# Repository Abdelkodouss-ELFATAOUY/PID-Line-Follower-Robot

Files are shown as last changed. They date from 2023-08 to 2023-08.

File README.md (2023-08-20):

# PID-Line-Follower-Robot
Study and production of a line follower with PID regulation: 
- ✓ Line follower with PID.
- ✓ Control by smartphone. 
- ✓ Detector of obstacles in an environment.



# IR Matrix Sensor


# video 
- Robot Finale :
- https://github.com/Abdelkodouss-ELFATAOUY/PID-Line-Follower-Robot/assets/142337040/76032142-d66d-45df-a297-c0f8cd918390
- https://github.com/Abdelkodouss-ELFATAOUY/PID-Line-Follower-Robot/assets/142337040/5c52f689-e024-426b-826d-6eb9a237bb47

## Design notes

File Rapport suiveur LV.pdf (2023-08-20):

UNIVERSITE SULTAN MOULAY SLIMANE

FACULTE DES SCIENCES ET TECHNIQUES

BENI-MELLAL

Licence Ingénierie Electronique et Télécommunication

Rapport de Projet de Fin d’Etudes

Présenté par

ELFATAOUY Abdelkodouss

AHARHAR Mohammed

Réalisé au sein de la FST Béni-Mellal

Encadré par : Pr. El-Hocine AGOURIANE

Soutenue publiquement le JJ /06/2021 devant le jury :

Etude et réalisation d’un suiveur de piste avec régulation PID

NOM1 | Président
NOM2 | Examinateur
Pr. El-Hocine AGOURIANE | Encadrant

Remerciement

En premier lieu, nous tenons à remercier ‹‹ DIEU › › pour nous avoir donner le courage et la

patience durant nos années d’études.

En second lieu, nous adressons nos reconnaissances à notre encadrant AGOURIANE EL-

Hocine Professeur à la faculté des sciences et techniques Béni-Mellal pour son aide précieuse,

son encadrement de qualité et ses directives qui nous ont été d’une grande utilité afin

d’accomplir notre projet de fin d’études.

Nous tenions également à remercier le professeur L. OUFNI chef du département de physique,

pour avoir permis de mener ce travail dans de bonnes conditions.

Enfin, nous exprimons nos remerciements, les plus dévoués, au professeur MABROUKI

Mustapha responsable de la formation ainsi qu’aux membres de jury pour avoir accepté de

juger notre modeste projet de fin d’études.

Dédicace

Nous dédions ce modeste travail

À nos chers parents

pour leur soutien, leur patience, leur sacrifice,

et leur amour, vous méritez tout éloge.

Vous qui avez fait de nous ce que nous sommes aujourd’hui.

Nous espérons être l’image que vous avez fait de nous, que dieu vous garde et vous bénisse.

Nous dédions aussi ce travail à nos chers frères et sœurs,

pour leur affection et leur encouragement qui ont toujours

été pour nous des plus précieux.

Que ce travail soit pour vous le gage de notre profond amour.

A tous nos amis,

A tous ceux qui nous ont aidés,

A tous ceux que nous aimons, nous dédions ce travail.

Sommaire

Chapitre II : L’étude du régulateur PID et description de fonctionnement du suiveur de piste

III.3.2. Installation du robot manuellement sur une piste et réglage des coefficients du régulateur PID à

Résume

Le but de ce projet est l’étude et la réalisation d’un robot autonome avec PID,

capable de suivre une piste et éviter les obstacles, offrant la possibilité de le commander

en utilisant un mode Bluetooth de contrôle à distance. Ce robot est à base d'un

microcontrôleur Arduino Uno, de capteurs de lumières, capteur ultrasonique ainsi que d’un

driver de puissance pour alimenter les moteurs qui assurent le déplacement du robot à

travers le mécanisme que nous avons réalisé. Son rôle est de développer les capacités

d'action des humains dans des environnements hostiles ou inaccessibles, et transporter les

produits dans le domaine industriel.

Liste des tableaux

TABLEAU 1: CARACTERISTIQUES DE LA CARTE ARDUINO UNO _______________________________________ 26 TABLEAU 2:TABLEAU : LE FONCTIONNEMENT DES BROCHES ________________________________________ 29 TABLEAU 3:LA TABLE DE VERITE DE FONCTIONNEMENT DE CONTROLE D’UN MOTEUR ___________________ 30 TABLEAU 4: FONCTION DE SUIVEUR DE PISTE ____________________________________________________ 38 TABLEAU 5:LES DEFAUTS DE ROUE DE GUIDAGE __________________________________________________ 46 TABLEAU 6: DESCRIPTION LES DIFFERENTS TYPES DE COMMUNICATION ______________________________ 48 TABLEAU 7:LES CAPTEURS INFRAROUGES IR _____________________________________________________ 50 TABLEAU 8:LES BROCHES DE CAPTEUR ULTRASON : _______________________________________________ 50 TABLEAU 9:LES BROCHES DE CAPTEUR ULTRASON : _______________________________________________ 50 TABLEAU 10:LES BROCHES DE CARTE BLUETOOTH ________________________________________________ 51 TABLEAU 11:LA CONNEXION ENTRE ARDUINO ET DRIVER MOTEUR DU PONT H_________________________ 51 TABLEAU 12: DESCRIPTION DE DIFFERENTES TACHES DE ROBOT _____________________________________ 53

Liste des figures

FIGURE 1:QUELQUES APPLICATIONS DES ROBOTS MOBILES __________________________________________ 4 FIGURE 2:DIFFERENTES STRUCTURES MECANIQUES DES ROBOTS _____________________________________ 5 FIGURE 3:REPONSE D’UN CAPTEUR ANALOGIQUE__________________________________________________ 6 FIGURE 4:REPONSE D’UN CAPTEUR NUMERIQUE __________________________________________________ 6 FIGURE 5:REPONSE D’UN CAPTEUR LOGIQUE _____________________________________________________ 7 FIGURE 6:FONCTIONNEMENT D'UN ACTIONNEUR__________________________________________________ 7 FIGURE 7:SCHEMA BLOC DU MOTEUR REDUCTEUR ________________________________________________ 8 FIGURE 8:ASSERVISEMENT DE SYSTEME_________________________________________________________ 12 FIGURE 9:LA STABILITE D'UN SYSTEME__________________________________________________________ 12 FIGURE 10: LA PRECISION D'UN SYSTEME _______________________________________________________ 13 FIGURE 11: LA RAPIDITE D'UN SYSTEME_________________________________________________________ 13 FIGURE 12:AOP NON INVERSEUR ______________________________________________________________ 14 FIGURE 13:PROPORTIONNALITE D’ERREUR ______________________________________________________ 14 FIGURE 14: L’ERREUR ENTRE LA CONSIGNE DESIREE ET DE MESURE __________________________________ 15 FIGURE 15: AOP DERIVATEUR _________________________________________________________________ 15 FIGURE 16: LA DERIVEE D’ERREUR _____________________________________________________________ 16 FIGURE 17: STABILITE DE SIGNAL PAR ACTION DERIVEE ____________________________________________ 16 FIGURE 18: AOP INTEGRATEUR________________________________________________________________ 17 FIGURE 19: L’INTEGRATION D’ERREUR __________________________________________________________ 17 FIGURE 20: LA PRECISION DE SIGNAL PAR ACTION INTEGRAL________________________________________ 17 FIGURE 21: LE SYSTEME ASSERVI ANALOGIQUE INSERE PAR LE REGULATEUR. __________________________ 18 FIGURE 22: L’ECHANTILLONNAGE D’UN SIGNAL __________________________________________________ 18 FIGURE 23: SYSTEME ASSERVI NUMERIQUE______________________________________________________ 19 FIGURE 24: L’INTEGRALE NUMERIQUE __________________________________________________________ 20 FIGURE 25: LA DERIVE NUMERIQUE. ___________________________________________________________ 21 FIGURE 26:DIAGRAMME SCHEMATIQUE DU SUIVEUR _____________________________________________ 22 FIGURE 27:SCHEMA ELECTRONIQUE DU CAPTEUR INFRAROUGE _____________________________________ 23 FIGURE 28: SCHEMA BLOC DE FONCTIONNEMENT DU CAPTEUR A ULTRASON __________________________ 24 FIGURE 29: STRUCTURE DE LA CARTE ARDUINO UNO ______________________________________________ 25 FIGURE 30: LE CAPTEUR BLUETOOTH HC-06 _____________________________________________________ 27 FIGURE 31: LES PILES DE LITHIUM______________________________________________________________ 27 FIGURE 32: L’EMPLACEMENT DU DRIVER DANS LA CHAINE. _________________________________________ 28 FIGURE 33: DESCRIPTION DIFFERENTE COMPOSANTES DU DRIVER MOTEUR ___________________________ 28 FIGURE 34: SCHEMA ELECTRONIQUE DE PONT EN H_______________________________________________ 29 FIGURE 35: SCHEMA BLOC DE FONCTIONNEMENT DES ENGRENAGES _________________________________ 30

FIGURE 36: LA COUPE DU MOTEUR MCC ________________________________________________________ 31 FIGURE 37: APP INVENTOR ET LANGAGE SCRATCH ________________________________________________ 32 FIGURE 38: LES PIECES DE ROBOT______________________________________________________________ 34 FIGURE 39: LE MONTAGE DE CHASSIS DE ROBOT _________________________________________________ 34 FIGURE 40: LES CARTES ELECTRONIQUES ________________________________________________________ 35 FIGURE 41: CAPTEUR INFRAROUGE ____________________________________________________________ 36 FIGURE 42: SIMULATION SOUS ISIS DU CAPTEUR AVEC UN MOTEUR__________________________________ 36 FIGURE 43: LE ROBOT SUIVEUR DE PISTE ________________________________________________________ 37 FIGURE 44: LE PROBLEME DE CONNEXION DES CAPTEURS INFRAROUGE ______________________________ 40 FIGURE 45: CIRCUIT IMPRIME DES CAPTEURS INFRAROUGES ________________________________________ 40 FIGURE 46: APPLICATION POUR CONTROLER LE ROBOT PAR BLUETOOTH______________________________ 41 FIGURE 47: ASPECT DE L’APPLICATION ANDROID REALISEE _________________________________________ 41 FIGURE 48: ALGORITHME DE L’APPLICATION BLUETOOTH __________________________________________ 43 FIGURE 49: LE ROBOT NE DETECTE PAS L’OBSTACLE _______________________________________________ 43 FIGURE 50: ASPECT ET FONCTIONNEMENT DU CAPTEUR ULTRASON__________________________________ 43 FIGURE 51: ILLUSTRATION DE FONCTIONNEMENT DU CAPTEUR _____________________________________ 44 FIGURE 52: LA STRUCTURE DE BRANCHEMENT DU CHARGEUR ______________________________________ 45 FIGURE 53: LE CHARGEUR DE BATTERIE LITHIUM REALISE __________________________________________ 45 FIGURE 54: LA STRUCTURE DE CHARGER DES PILES________________________________________________ 46 FIGURE 55: LA CONFIGURATION DE LA BATTERIE REALISEE. _________________________________________ 46 FIGURE 56: SCHEMA SYNOPTIQUE DE L’ENSEMBLE DU SUIVEUR DE PISTE _____________________________ 48 FIGURE 57: LE BRANCHEMENT DES COMPOSANTS DU ROBOT PAR LOGICIEL FRITZING ___________________ 50 FIGURE 58: VUE AU-DESSOUS DE ROBOT ________________________________________________________ 52 FIGURE 59:VUE AU-DESSUS DE ROBOT__________________________________________________________ 52 FIGURE 60: LES MULTITACHES DE ROBOT _______________________________________________________ 53

Introduction générale

Depuis bien longtemps, l’Homme rêve de créer des machines intelligentes capables

d’effectuer des tâches à sa place. Ainsi, les humains auraient plus de temps à consacrer

pour leurs loisirs, ou prendraient moins de risques pour effectuer des tâches dangereuses

dans des endroits inaccessibles et hostiles. La robotique est l’ensemble des techniques

permettant la conception et la réalisation de ces machines appelées « robots ». Un robot est

un appareil effectuant, grâce à un système de commande automatique à microprocesseur,

une tâche précise pour laquelle il a été conçu dans le domaine industriel, domestique ou

scientifique.

Dans ce travail on va se focaliser sur les robots mobiles, qui sont largement utilisés

dans les environnements industriels, le plus souvent pour effectuer des tâches répétitives

et pénibles. L’intérêt principal des robots mobiles est de permettre aux êtres humains

d’effectuer des tâches dangereuses dans des endroits inaccessibles. C’est pour cela que

l’un des domaines les plus populaires où les robots mobiles sont utilisés est le domaine

scientifique.

Afin d’être autonome, un robot mobile doit posséder de nombreuses capacités.

Premièrement, il doit être capable de percevoir son environnement et de se localiser dans

celui-ci. Pour ce faire, il doit être doté de plusieurs capteurs. Une fois localisé dans son

environnement, le robot doit être capable de se déplacer d’un point à un autre en trouvant

des chemins dégagés et sécurisés afin d’éviter des collisions avec les obstacles, pour cela

les robots mobiles utilisent plusieurs moyens de locomotion selon l’environnement auquel

ils sont destinés. De plus, un robot est appelé à communiquer avec son environnement ou

avec des agents situés à proximité et cela peut être fait par une interface wifi,

Bluetooth…etc.

Le but de ce travail est la conception et réalisation d’un suiveur de piste doté d’une

régulation PID en plus télécommandé à distance par Bluetooth et qui a la possibilité de

détecteur des obstacles et d’être autonome. Pour le réaliser on a utilisé une carte Arduino

UNO qui représente le cerveau du robot munis de différents capteurs qui vont lui permettre

la perception, il sera doté de moteurs et roues pour le déplacement, puis un régulateur PID qui pilote le suiveur de piste afin d’amélioration les performances, ainsi qu’un moyen de

communication par voie Bluetooth qui offre une possibilité de contrôle à distance.

Ce travail est organisé de la façon suivante :

- Le premier chapitre est consacré à des généralité sur les robots mobiles et la

structure robotique.

- Le deuxième chapitre présente la notion de système asservis et l’étude de la

régulation automatique PID.

- Le troisième chapitre est dédié à la réalisation et conception du robot suiveur

de pise.

Chapitre I : Généralités sur la Robotique

## Chapitre I : Généralités sur la Robotique

Introduction

La robotique est une science à la croisée de plusieurs disciplines scientifiques et

techniques (informatique, mécanique, automatique et électronique) permettent la

conception et la réalisation des robots qui vise à rendre une machine autonome.

I.1. Généralités sur les robots mobiles

Les robots mobiles sont des robots capables de se déplacer dans leur

environnement.

I.1.1. Définition d’un robot mobile

Un robot est une machine qui est équipée de capacités de perception, de décision et

d’action qui lui permettent d’agir de manière autonome dans son environnement en

fonction des informations collectées par ses différents capteurs.

L’appellation Robot mobile regroupe aussi un ensemble de programmes associés,

dont les mouvements sont synchronisés et commandés numériquement. Il n’est donc

qu’une machine programmable qui ne fait qu’exécuter ce que l’homme lui a programmé.

I.1.2. Classification des robots mobile

La classification des robots mobiles se fait selon plusieurs critères :

- Degré d'autonomie ;
- Système de locomotion ;
- Énergie utilisée.

La classification la plus intéressante et la plus utilisée est selon le degré

d'autonomie. Un robot mobile autonome est un appareil capable de se déplacer par ses

propres moyens, dotés de capacités décisionnelles et de moyens d'acquisition et de

traitement de l'information qui lui permettent d'accomplir, sous un contrôle humain réduit,

un certain nombre de tâches dans un environnement complètement inconnu.

I.1.3. Types de robots :

- Robot télécommandé par un opérateur :

Chapitre I : Généralités sur la Robotique

Ces robots sont commandés par un opérateur qui leur impose chaque tâche élémentaire

à réaliser.

- Robot télécommandé au sens de la tâche à réaliser :

Le véhicule contrôle automatiquement ses actions.

- Robot semi- autonome :

Ce type de robot réalise des tâches prédéfinies.

- Robot autonome :

Ce type de robot réalise des tâches semi-définies, il pose des problèmes d’un niveau

de complexité élevé de représentation des connaissances, de capacité décisionnelle et de

génération de plans qui sont résolus à bord dans la mesure du possible.

I.1.4. Les applications

Les applications des robots sont diverses et dons plusieurs domaines.

- Véhicules autoguidés ou VAG (https://www.mecalux.fr/cours-logistique-entrepot/engins-de-manutention/vehicule-a-guidage-automatique-agv-vga)
- Robot explorateur
- Robot de service
- Robot ludique
- Robot de Surveillance
- Robot mobile de tri
- Robot quadrupède

Figure 1:Quelques applications des robots mobiles

I.1.5. Les avantages dans l’utilisation du robot mobile

L'utilisation de robots mobiles présente ces principaux avantages :

Robot AVG | Robot explorateur | Robot de tri

Chapitre I : Généralités sur la Robotique

- Remplacement de l’homme dans l’exécution des tâches complexes et

répétitives.

- Accroissement de la capacité de production.
- Déplacement sans conducteur.

I.2. La structure mécanique et motricité

Il existe quatre types de structures mécaniques assurant la motricité des robots :

- Les robots à roues.
- Les robots à chenilles.
- Les robots marcheurs.
- Les robots à pattes.

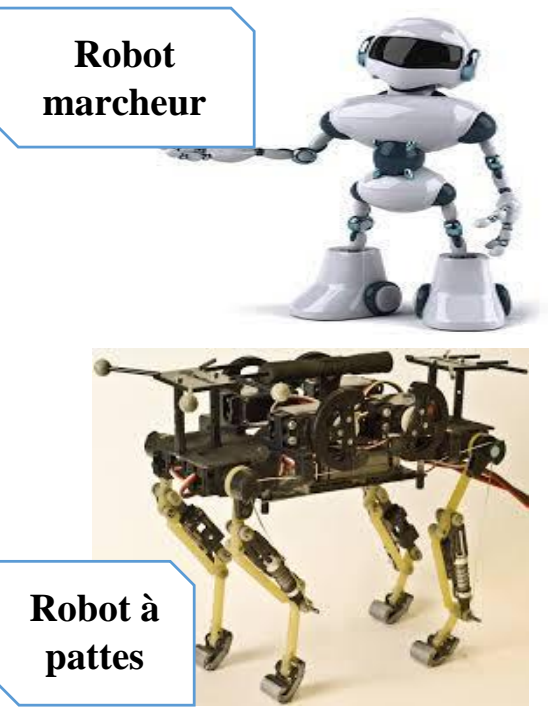
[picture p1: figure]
Robot marcheur; Robot à pattes

Figure 2:Différentes structures mécaniques des robots

I.3. Les composants d’un robot

Un robot mobile est constitué de composantes matérielles et logiciels. Parmi ces

composants on retrouve les capteurs, les actionneurs, carte de traitement et une source

d’énergie.

I.3.1 Les capteurs

Les capteurs sont des transducteurs qui permettent d’acquérir des données

provenant d’environnement pour mesurer une grandeur physique (température, obstacle,

Chapitre I : Généralités sur la Robotique

vitesse, humidité, pression, niveau, débit, ...) en générale en la transformant en une

grandeur électrique.

I.3.1.1 Classification des capteurs

Selon la nature du signal ou l’information de sortie des capteurs on peut les classer

en trois catégories :

I.3.1.1.1 Le signal analogique

L’information peut prendre toutes les valeurs possibles entre deux certaines valeurs

limites pouvant être courant ou tension, on parle alors d’un capteur analogique.

Figure 3:Réponse d’un capteur analogique

I.3.1.1.2 Le signal numérique (https://fr.wikipedia.org/wiki/Num%C3%A9rique)

L’information fournie par le capteur est un nombre binaire codé sur n bits pouvant

être un train d’impulsion, code numérique binaire. On parle alors d’un codeur numérique.

Figure 4:Réponse d’un capteur numérique

Chapitre I : Généralités sur la Robotique

I.3.1.1.3 Le signal logique

L’information ne peut prendre que la valeur 1 ou 0. On parle alors d’un détecteur

Tout Ou Rien "TOR". Il est très répondu dans les systèmes automatisés et est classé en

deux familles :

- Capteurs avec contact ou détecteur de position.
- Capteurs sans contact ou détecteurs de proximité.

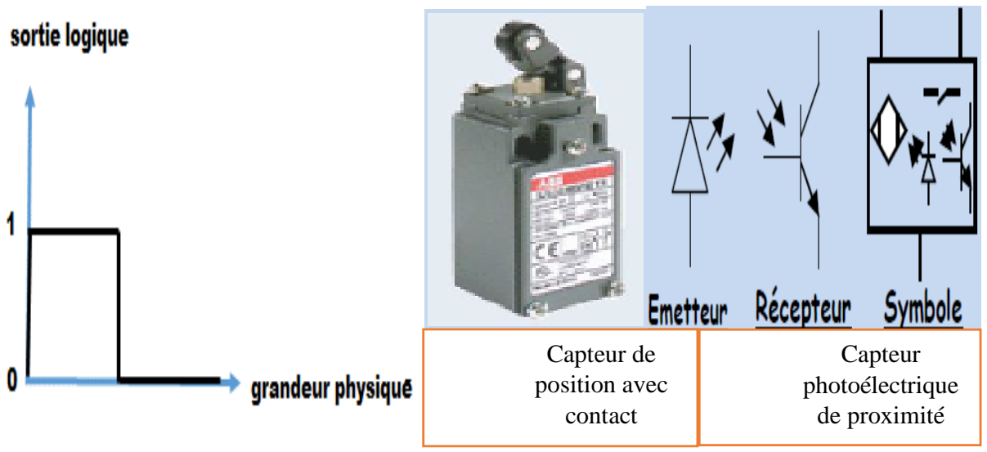
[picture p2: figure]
Capteur photoélectrique de proximité; Capteur de position avec contact

Figure 5:Réponse d’un capteur logique

I.3.2 Les actionneurs

Les actionneurs sont situés dans la partie opérative d’un système automatisé. Ils

font partie de la chaine d’action de ce système. Les actionneurs transforment l’énergie de

puissance fournie du système en énergie mécanique pour déplacer une machine.

Figure 6:Fonctionnement d'un actionneur

I.3.2.1 Le type d’actionneurs I.3.2.1 1 Moteur à courant continue

Un moteur continu appelé également moteur DC, transforme une énergie

électrique en une énergie mécanique. Il sert notamment à faire tourner les roues d'un

système de façon "constante".

Energie | Actionneur
électrique

Energie
mécanique

Energie de
contrôle

Chapitre I : Généralités sur la Robotique

Son Inconvénient est son faible couple mécanique. Pour augmente le couple il faut

Figure 7:Schéma bloc du moteur réducteur

- Pe
: Puissance électrique.
- Pm : Puissance mécanique.
- R : le rapport de réduction.
- r< 1 : réduit la vitesse angulaire.
- r> 1 :multiplie la vitesse angulaire.
- Pe=UI=Pm=Cmωe

→ Cm=

Pe
| ωe
Pour augmenter le couple il faut diminuer la vitesse angulaire.

I.3.2.1.2 Servomoteur

Un servomoteur est un moteur continu équipé d'un réducteur (des engrenages),

dont l'objectif est de réduire la vitesse et d'augmenter le couple (la puissance), il est doté

d’un potentiomètre qui permet au servomoteur de garder l’angle d’inclinaison choisit. En

effet, l’un des intérêts des servomoteurs c’est de leur faire prendre et garder un angle.

Pour contrôler un servomoteur, il suffit de lui envoyer une impulsion de quelques

millisecondes qui se répète à intervalle régulier (ce que l’on appelle la période), et dont

la durée détermine l’angle de rotation de l’axe du servomoteur.

Par exemple une impulsion de:

1,25 ms = 0 degré

1,50 ms = 90 degrés

1,75 ms = 180 degrés

Chapitre I : Généralités sur la Robotique

Conclusion

Dans ce chapitre a étalé les notions de base de la robotique mobile, quelques types

d’applications et de classification ont été présentés. Dans la suite certains points seront

détaillés, car ils sont plus étroitement liés au présent projet.

Chapitre II : L’étude de régulateur PID et Description de fonctionnement du suiveur de piste

## Chapitre II : L’étude du régulateur PID et description de fonctionnement du suiveur de piste

Introduction

Pour être compétitif, un procédé industriel doit être obligatoirement automatisé. En

effet, la compétitivité exige de le maintenir le plus près possible de son optimum de

fonctionnement prédéfini par un cahier des charges qui fixe les conditions et performances

imposées. La régulation occupe généralement la grande partie de l’automatisation d’un

procédé industriel. Actuellement, il est impossible de rencontrer un procédé industriel

n’utilisant pas de régulation. Cela veut dire que la régulation industrielle est plus

qu’indispensable pour le bon fonctionnement et donc pour la compétitivité de tout procédé

industriel. Le contrôle en boucle fermée, régulation ou asservissement, est le plus populaire

au sein de la majorité des industriels. Dans le cadre de notre projet de fin d’études,

l’objectif du travail qui nous a été proposé est de faire l'étude de la régulation

proportionnelle, intégrale, dérivée ou PID sur le suiveur de piste afin d’optimiser les

performances du suiveur de piste.

Dans ce chapitre, après un bref historique sur la régulation PID, nous allons donner

quelques rappels sur l’asservissement et sur la régulation et leurs objectifs. Nous allons

aussi discuter sur la typologie de la régulation qui comprend deux types : régulation

analogique et régulation numérique qui ont le même principe de fonctionnement.

Partie I : Généralités sur la régulation PID : analogique et Numérique

II.1 Historique de contrôleur PID

Nicolas Minorsky est né en septembre1885 à

Korcheva, Russie et il est mort à l’âge de 85 ans le 31 juillet

1970, en Italie. I a fait ses études à l’école navale. Il a fait des

études en génie électrique et en sortit en 1914 avec un doctorat

en sciences appliquées, il a servi dans la Marine russe et a été

pendant un an adjoint et il a immigré vers l’américain et a

travaillé dans le domaine de l’électronique et de la physique

applique en tant que professeur universitaire. Pendant la guerre il a travaillé en grande

Chapitre II : L’étude de régulateur PID et Description de fonctionnement du suiveur de piste

partie sur des problèmes de stabilité, c’est durant cette période qu’il s’intéressé de plus en

plus aux systèmes non linéaires. En 1946 il rejoint la division de l’ingénieure mécanique

pour continuer à travailler sur les problèmes de stabilisation des navires, sur son article

« stabilité directionnelle des corps a direction automatique » Minorisky intervient au

croisement de trois domaines : La mécanique, l’électricité et les mathématiques.

Minorsky a étudié le comportement mathématique des équations différentielles de

mécanisme des navires c’est pour trouver des paramètres principaux au domaine

d’électricité afin de piloter des navires automatiquement.

II.2 Définition de l’automatique.

L'automatique est une science qui traite de la modélisation, de l'analyse, de l'

identification et de la commande des systèmes dynamiques.

Un automaticien doit être à la fois :

- Mathématicien.
- Electricien.
- Mécanicien.
- Informaticien.

II.2.1 Système automatisé

Un système automatisé est un système réalisant des opérations et pour lequel

l'homme n'intervient que dans la programmation du système et dans son réglage.

II.2.2 Système linéaire et non linéaire.

Dans les Systèmes linéaires les lois mathématiques entre l'entrée et la sortie sont

des équations différentielles linéaires à coefficient constante. Un système linéaire possède

les propriétés de superposition et de proportionnalité.

Le principe de superposition permet de décomposer l'étude de systèmes complexes

en sous-systèmes plus simples à étudier.

Dans les systèmes non linéaires les lois mathématiques entre l'entrée et la sortie

sont des équations différentielles non linéaires, et dans ce cas on ne peut pas appliquer le

principe de superposition. Il est difficile de les résoudre en temps continue on peut les

simplifier par des approximations numériques en temps discret.

II.4 Notion de système asservi.

Les Systèmes asservis (contre-réaction) possèdent des entrées qui sont ajustée en

réaction aux informations de sortie, comme le schématise le schéma bloc de figure 8.

Chapitre II : L’étude de régulateur PID et Description de fonctionnement du suiveur de piste

Figure 8:Asservisement de système

Un système asservi a pour objectif de :

- Limiter au mieux l’erreur entre la consigne désirée et la consigne de mesure.
- Diminuer au mieux l’effet de perturbation sur la sortie.

II.5. La régulation dans l’automatique

La régulation regroupe l'ensemble des techniques qui permettent de contrôler

une grandeur physique, (https://fr.wikipedia.org/wiki/Grandeur_physique) afin d’optimiser les performances du système asservi.

II.5.1. Les performances d’un système asservi :

Stabilité : c’est la faculté de système asservi de revenir à sa position de repos suite

à une perturbation de courte durée.

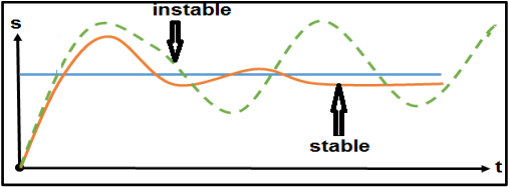
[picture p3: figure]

Figure 9:La stabilité d'un système

Chapitre II : L’étude de régulateur PID et Description de fonctionnement du suiveur de piste

Précision : c’est l’erreur entre la consigne désirée et la consigne mesurée. Si l’erreur

est faible la précision est grande.

Figure 10: La précision d'un système

Rapidité : elle peut être mesurée par le temps de stabilisation ou de réponse qui est

le temps nécessaire pour atteindre le régime final à ∓5% près, suite à une perturbation ou

à une variation de la consigne.

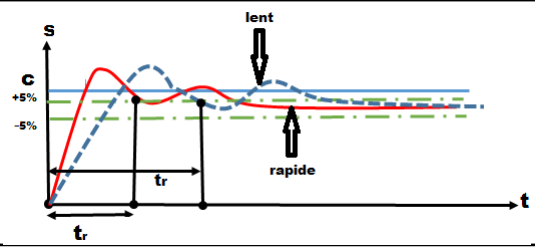
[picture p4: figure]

Figure 11: La rapidité d'un système

II.6. Classification selon le type de régulateur

On peut classer la régulation d’un système en deux catégories ça dépend de la

nature du système numérique ou analogique.

II.6.1. Le Régulateur analogique (d’un système continu).

Un système est dit continu lorsque les grandeurs le caractérisant délivrent une

information à chaque instant donc continu dans le temps.

La régulation permet de maintenir une grandeur physique à une valeur constante

quelques soient les perturbations extérieures. L'objectif global de la régulation peut se

Chapitre II : L’étude de régulateur PID et Description de fonctionnement du suiveur de piste

résumer par ces trois mots clefs : Mesurer, Comparer et Corriger. Généralement Pour

améliorer les performances d’un système asservi, on insère dans la chaine directe du

système un correcteur PID.

II.6.1.1. Le régulateur PID

Généralement il est composé par trois actions pour améliorer le système.

i. Action P

C’est une action proportionnelle qui est schématisé par le circuit électronique

analogique non inverseur de la figure 14.

P : l’action proportionnelle agit de manière instantanée, donc rapide. Afin de

diminuer l’écart de réglage et rendre le système plus rapide, on augmente le gain (figure

13) mais, on est limité par la stabilité du système.

Le régulateur p est utilisé lorsqu’on désire régler un paramètre dont la précision

n’est pas importante.

Figure 12:AOP non inverseur

Figure 13:Proportionnalité d’erreur

1 +

R2
ε(t) | R1 | s(t)

Chapitre II : L’étude de régulateur PID et Description de fonctionnement du suiveur de piste

On remarque que le signal de commande S évolue par l’action du coefficient

correcteur Kp.

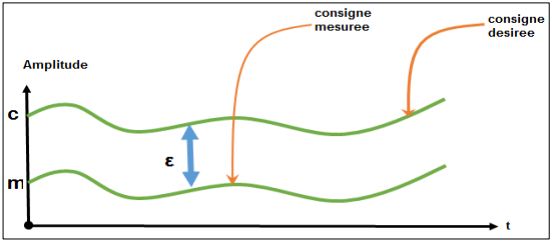
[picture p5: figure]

Figure 14: l’erreur entre la consigne désirée et de mesure

Pour corriger erreur il faut multiplier erreur par un coefficient Kp qui augmente le

gain afin d’améliorer la rapidité (la vitesse) du système, et lorsque la vitesse augmente le

temps de réponses(tr)diminue.

ii. Action D

C’est une action de dérivée qui est réalisée par un montage électronique analogique

dérivateur (Figure15).

L’action dérivée permet d’accélérer la réponse du système et améliore la stabilité

de la boucle, en permettant notamment un amortissement rapide des oscillations dues à

l’apparition d’une perturbation ou à une variation subite de la consigne.

L’action D est utilisée dans l’industrie pour le réglage des variables lentes.

Figure 15: AOP dérivateur

ε(t)

R2C1

d.
dt | s(t)

Chapitre II : L’étude de régulateur PID et Description de fonctionnement du suiveur de piste

Figure 16: La dérivée d’erreur

Le signal de commande s de la figure 18 est proportionnel à la dérive du signal

d’erreur ce qui permet de diminuer le dépassement du signal par rapport à la consigne

désirée afin de stabiliser le système, cette action qui empêche l’erreur d’évoluer au cours

du temps.

Figure 17: Stabilité de signal par Action dérivée

iii. | Action I
| C’est une action intégrale qui est modélisée par un modèle électronique analogique

intégrateur (Figure18).

| L’action intégrale complète l’action proportionnelle. Elle permet d’éliminer l’erreur

résiduel en régime permanent.

| L’action intégrale est utilisée lorsque on désire avoir en régime permanent une

précision parfaite.

Kd d..
dt
Le Signal instable | Le signal stable

න.

Chapitre II : L’étude de régulateur PID et Description de fonctionnement du suiveur de piste

Figure 18: AOP intégrateur

Figure 19: l’intégration d’erreur

La sortie de commande S c’est l’intégration d’erreur en régime permanant

(statique) d’un système multiplie par un coefficient d’intégrale Ki

Figure 20: La précision de signal par Action intégral

II.6.1.2. Le système asservi continue avec régulateur PID

1
R1C1
ε(t) | s(t)

Ki න.

Le Signal n’est pas précis | Le Signal est précis

Chapitre II : L’étude de régulateur PID et Description de fonctionnement du suiveur de piste

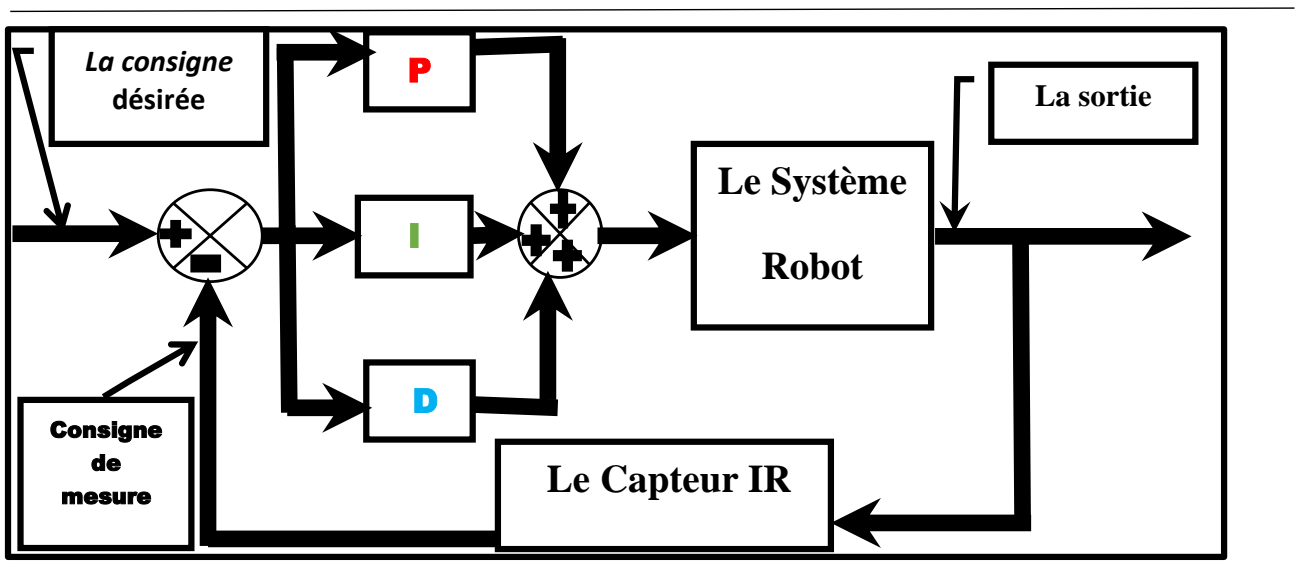
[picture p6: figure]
Le Système; Robot; Le Capteur IR; La consigne; désirée; La sortie; Consigne; mesure

Figure 21: Le système asservi analogique inséré par le régulateur.

La structure la plus utilisé du régulateur PID est une architecture en parallèle pour que les

actions P, I et D agissent en même temps ce qui procure au système une grande rapidité.

II.6.2. Le Régulateur numérique.
Le régulateur numérique est une unité numérique qui agit comme un contrôleur de

système. Il est essentiellement utilisé en tant que système de retour d’information.

Généralement, il est comme un calculateur numérique qui exécute un algorithme qui

permet de réaliser une tâche dans un programme pour optimiser les performances de

système.

II.6.2.1. Le signal échantillonné
Il s’agit d’un signal continu discrétisé par un pas de temps régulier. Ce pas est

appelé période d’échantillonnage.

Figure 22: L’échantillonnage d’un signal

Chapitre II : L’étude de régulateur PID et Description de fonctionnement du suiveur de piste

II.6.2.2. Le système asservi numérique avec régulateur PID

Transposition de la fonction de transfert du PID continu en un correcteur numérique

pour avoir un algorithme de PID numérique qui s’approche le plus possible du

comportement du contrôle numérique.

II.6.2.2.1. Structure générale d’un asservissement numérique d’un système analogique

Les Convertisseurs Analogique-Numérique (CAN) et Numérique-Analogique

(CNA) sont indispensables au fonctionnement des systèmes asservis par Calculateur

Numérique (CN). La liaison du calculateur avec son environnement externe est effectuée

par ces convertisseurs. La figure 23 montre un système asservi par un calculateur

numérique (CN). Il s’agit d’un asservissement numérique d’un processus analogique.

Figure 23: Système asservi numérique

Dans cette structure, on distingue :

- Un calculateur numérique (CN) : tout moyen de calcul automatique permettant d’effectuer des opérations arithmétiques ou analytiques suivant un programme déterminé qui est exécuté pas à pas, comme : un contrôleur numérique PID.
- Un capteur analogique permettant la mesure de la grandeur de sortie. En effet, un capteur permet de convertir une grandeur physique en grandeur électrique.
- Un convertisseur analogique-numérique (CAN) : un CAN permet la transformation d’une grandeur analogique en grandeur numérique.
- Un convertisseur numérique-analogique (CNA) : un CNA permet de transformer une grandeur numérique en grandeur analogique.
- Un système analogique : installation que l’on veut piloter : Robot (suiveur de piste)
- Un comparateur qui permet de produire le signal d’erreur ε(t) à partir de l’état actuel et de la valeur de consigne.

Chapitre II : L’étude de régulateur PID et Description de fonctionnement du suiveur de piste

II.6.2.3. Le régulateur PID
- Transposition des contrôleurs PID analogiques.

Afin de pouvoir importer un régulateur PID analogique dans un calculateur

numérique, il faut le transposer (Numériser) en utilisant les différentes techniques de

discrétisation.

On fait l’approximation des méthodes numérique de subdiviser le signal analogique

par méthode d’échantillonnage en respectant la condition de Nyquist-Shannon pour

reconstruire le signal qui est : Fe ≥ 2Fmax

- Approximation numérique d’Intégrale rectangulaire.

Cette méthode numérique consiste à approximer l’aire sous une courbe à l’aide des

sommes d’aires de rectangles dont les hauteurs sont calculées.

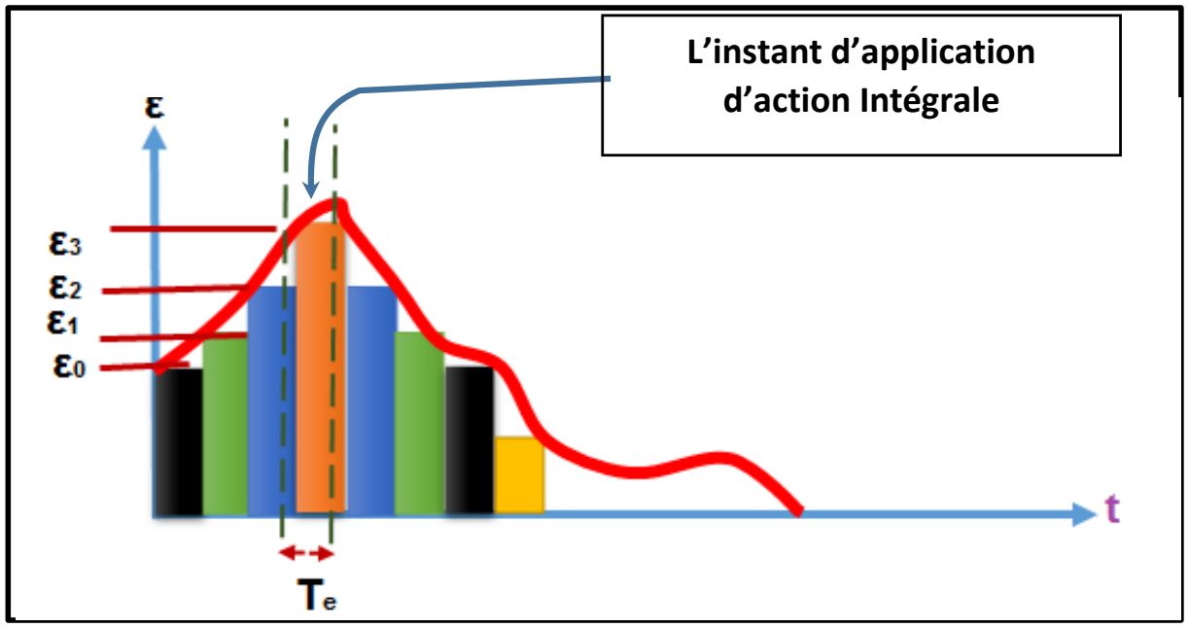
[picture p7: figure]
L’instant d’application d’action Intégrale

Figure 24: L’intégrale numérique

Action d’intégrale a l’instant t c’est l’intégrale du passé plus l’intégrale a instant

présent.

- La discrétisation numérique de dérivée par méthode d’Euler arrière.

## I = Ip + ε3 × Te

Ip

## = ε2 × Te + ε1 × Te + ε0 × Te

Chapitre II : L’étude de régulateur PID et Description de fonctionnement du suiveur de piste

Cette approche consiste à approximer la dérivée continue entre deux instants

Figure 25: La dérive numérique.

Conclusion

Dans cette partie on a présenté le principe de la régulation PID des systèmes

automatiques. Nous avons établis les formules de calcule I et D par l’approximation

numérique par le calculateur numérique et on considère Te comme un élément neutre

parce qu’il n’a pas des effets sur I et D dans la programmation algorithmique.

Donc D = ε(k) − ε(k − 1) et I = Ip + ε(k) et P = ε(k)

Les termes de régulateur PID sont :

D =

ε5 − ε4

Te

Pterme = Kp × P

Iterme = KI × I

Dterme = KD × D

Chapitre II : L’étude de régulateur PID et Description de fonctionnement du suiveur de piste

Partie II : Le fonctionnement et description du suiveur de piste II.1. Cahier de charge et analyse fonctionnelle du suiveur de piste

II.1.1. Cahier de charge

Le suiveur de piste doit être réalisé autour d’une structure mécanique qui permet

d’assurer la motricité du robot, il doit être de type à quartes roues pour une meilleure

stabilité. Et un châssis qui peut transporter toutes les composantes du système. Pour une

meilleure performance le suivie de piste doit être optimiser en utilisant une régulation PID.

II.1.2 Structure et constituants du suiveur

Pour réaliser ce projet nous avons proposé une solution utilisant une carte Arduino UNO comme

organe de commande et décision doté de plusieurs capteurs :

- Capteurs de lignes ce sont des capteurs infrarouges ;
- Capteur ultrasonique pour la détection d’obstacle ;
- Capteur Bluetooth pour la communication avec un smartphone.

Les roues du suiveur sont entrainées par des moteurs à courant continue commandés par un

driver de puissance. L’ensemble est alimenté par une alimentation autonome. Le digramme

schématique du suiveur est donné par la figure 26.

Figure 26:Diagramme schématique du suiveur

Chapitre II : L’étude de régulateur PID et Description de fonctionnement du suiveur de piste

II.1.2. 1. Le capteur infrarouge

Le capteur infrarouge est un capteur actif généralement constitue par deux

composants électroniques, il intègre l’émetteur qui est une LED qui émet un rayonnement

infrarouge et un récepteur qui est le phototransistor qui détecte les rayons infrarouges

réfléchis par un corps. Etant donné que la piste suivie par le robot est de couleur noir il n’y

a pas de réflexion, pratiquement les rayons qui sont émet par la diode sont absorbés par la

piste noir. La piste est placée sur un fond blanc, qui lui, réfléchi pratiquement toute la

lumière. Ce qui va permettre de différencier la piste du fond et permettre au

microcontrôleur par la suite de déterminer la position du robot par rapport à la piste.

Le schéma électrique du capteur de ligne est schématisé par la figure 27.

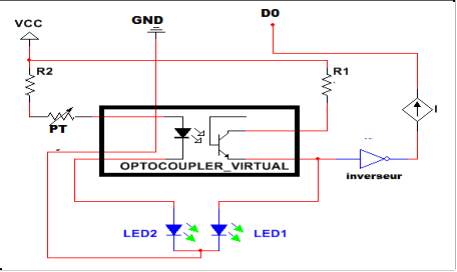
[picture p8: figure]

Figure 27:Schéma électronique du capteur infrarouge

Le potentiomètre permet de faire varier distance de détection de l’obstacle.

La led LED2 permet de signaler la détection d’un obstacle donc un corps qui réfléchis la

lumière c’est le cas du fond blanc de la piste.

II.1.2.2. Le capteur à ultrason

Le capteur à ultrason est un capteur qui génère des ultrasons qui sont des vibrations

acoustiques engendrées à hautes fréquence qui ne sont pas audible.

Chapitre II : L’étude de régulateur PID et Description de fonctionnement du suiveur de piste

Figure 28: Schéma bloc de fonctionnement du capteur à ultrason

Un générateur au niveau du capteur génère une onde ultrasonique qui va être

envoyée par transducteur, l’onde va se propagée et lorsqu’elle rencontre un obstacle une

partie est réfléchis vers le récepteur du capteur.

On sait que l’expression de la vitesse est : v =

D
t

donc la distance mesurée par le

capteur est : D = v × t/2 Telle que : t = taller + tretour avec taller : c’est le temps

d’arriver les ultrasons à l’obstacle. tretour : C’est le temps de retour au capteur.

La vitesse des ondes ultrasonique dans l’aire est : v = 340m⁄s

Après transformation on obtient : D(cm)~

| 1
| 58 × t(us)

Le principe de fonctionnement du capteur est entièrement basé sur la vitesse du son. (https://fr.wikipedia.org/wiki/Vitesse_du_son)

Voilà comment se déroule une prise de mesure :

a) On envoie une impulsion high de 10us sur la broche TRIGGER du capteur.
b) Le capteur envoie alors une série de 8 impulsions ultrasoniques à 40khz.
c) Les ultrasons se propagent dans l’aire jusqu’à toucher un obstacle et retourne dans

l’autre sens vers le capteur.

d) Le capteur détecte l’écho et clôture la prise de mesure.

Le signal sur la broche ECHO du capteur reste à HIGH durant les étapes c) et d),

ce qui permet de mesurer la durée de l’aller et retour des ultrasons et donc de déterminer

la distance.

Chapitre II : L’étude de régulateur PID et Description de fonctionnement du suiveur de piste

II.1.2.3. Unité de traitement

Arduino c’est donc une petite carte électronique équipée d’un microcontrôleur.

C’est une plateforme libre qui peut être programmé librement avec C++, il possède

plusieurs entrées et sorties numériques et analogiques. La figure 29 schématise la structure

de la carte Arduino.

Figure 29: Structure de la carte Arduino Uno

a) Alimentation d’Arduino

La carte Arduino Uno peut être alimentée via la connexion USB ou avec une

alimentation externe. La source d'alimentation est automatiquement sélectionnée. Une

alimentation externe peut provenir soit d'un adaptateur AC-DC ou d’une batterie connectée

dans le pin (ou broche) GND et V-IN (alimentation externe). Le processeur peut

fonctionner sur une alimentation externe de 6 à 20 volts. Cependant, si la tension est

inférieure à 7V, le pin 5V peut fournir moins de cinq volts et le processeur peut devenir

instable. Si la tension est supérieure à 12V, le régulateur de tension peut surchauffer et

endommager la carte. La plage recommandée est de 7 à 12 volts.

b) Les pins d'alimentation sont les suivantes
- VIN. Tension d'entrée à la carte Arduino à l'aide d'une source d'alimentation

externe (par opposition à 5 volts de la connexion USB ou une autre source

d'alimentation régulée).

Chapitre II : L’étude de régulateur PID et Description de fonctionnement du suiveur de piste

- 5V. Ce Pin délivre un 5V régulé par la carte. Le processeur peut être alimenté

soit à partir de la prise d'alimentation DC (7-12V), le connecteur USB (5V), ou

le pin V-IN de la carte (7-12V).

- 3.3V. Une alimentation de 3,3 volts générée par le régulateur. La

consommation de courant maximale est de 50 mA

- GND : Masse

Certaines broches (les pins) ont des fonctions spécialisées :

- Transmission Série : 0 (RX) et 1 (TX), permettent de recevoir (RX) et

transmettre (TX) en format TTL les données séries.

- Interruptions externes : 2 et 3. Ces broches peuvent être configurées pour

déclencher une interruption sur une valeur basse, un front montant ou

descendant ou un changement d’état.

- Impulsion PWM : Broches 3, 5, 6, 9, 10 et 11. Fournissent une impulsion PWM

(Pulse Width Modulation) c’est des sorties à rapport cyclique variables.

❖ On résume les caractéristiques d’Arduino dans le tableau ci-dessous :

Tableau 1: caractéristiques de la carte Arduino Uno

Microcontrôleur | ATmega 328
Tension d’entrée (recommande) | 7 – 12v
Tension d’entrée (limites) | 6 – 20v
Broches d’entrée analogique | 6
Broches d’E /S numériques | 14 (dont 6 fournissent une sortie PWM)
Courant CC par broche I/O | 40mA
Courant DC pour Pin 3.3v | 50mA
Mémoire flashe | 32Ko (ATmega 328)
Mémoire SRAM | 2Ko (ATmega 328)
Mémoire EEPROM | 1Ko (ATmega 328)
Vitesse de l’horloge | 16MHz

II.1.2.4. Capteur Bluetooth

Le module Bluetooth va permettre d'ajouter une liaison Bluetooth à notre projet.

Le capteur choisi c’est HC06 (figure 30) qui permet une communication via une liaison

série TTL.

Chapitre II : L’étude de régulateur PID et Description de fonctionnement du suiveur de piste

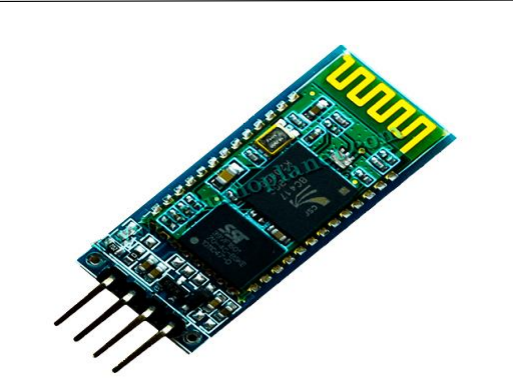
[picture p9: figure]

Figure 30: Le capteur Bluetooth HC-06

### Les caractéristiques techniques de ce capteur sont :

- Alimentation : 3,6 à 6 Vcc (régulateur 3 Vcc intégré)
- Bluetooth : 2.0
- Portée : jusqu'à 10 mètres
- Liaison série : 4800 à 1382400 bauds
- Antenne : 2,4 GHz intégrée
- Configuration via commandes AT.

II.1.2.5. Alimentation

Une pile ou un accumulateur électrique est un dispositif électrochimique qui

transforme une énergie chimique en énergie électrique. Notre s’est vite porté vers les piles

Lipo de lithium qui sont caractérisées par une grande stabilité, elle dure plus longtemps

donc une grande et se charge plus vite, cependant se sont les plus chers sur le marché.

Figure 31: Les Piles de lithium

Chapitre II : L’étude de régulateur PID et Description de fonctionnement du suiveur de piste

II.1.2.6. Le module driver de puissance pour alimenter les moteurs (L298N)

Le driver est basé sur le circuit L298N qui permet de contrôler 4 moteurs à courant

continus, il peut faire tourner les moteurs en vitesse continue ou en PWM (La modulation

de largeur d'impulsions (MLI) ou Pulse Width Modulation). De plus, il inclut des diodes

pour protéger le circuit. Des résistances de rappel et un dissipateur de chaleur en cas de

forte charge. L298N est un double pont en H c’est à dire qu’il permet de faire tourner les

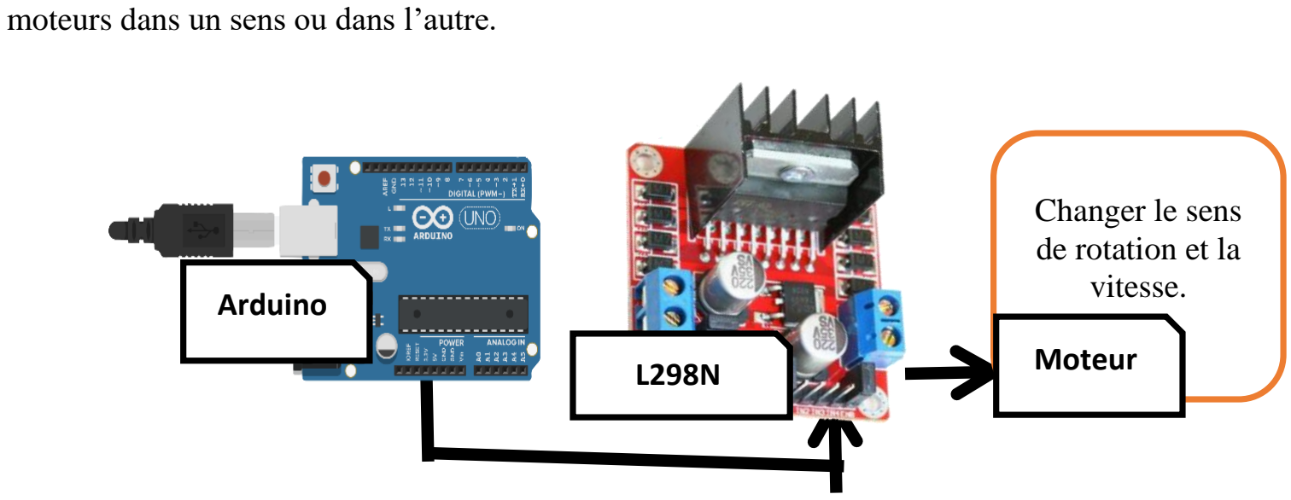
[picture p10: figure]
moteurs dans un sens ou dans l’autre.; Changer le sens de rotation et la vitesse. Arduino; Moteur

Figure 32: L’emplacement du driver dans la chaine.

a. Présentation du module L298N

La figure 33 permet de donner une idée de l’utilité des éléments constituants le module.

Figure 33: Description différente composantes du driver moteur

Chapitre II : L’étude de régulateur PID et Description de fonctionnement du suiveur de piste

Tableau 2:Tableau : Le fonctionnement des broches

Nom de Broche | Fonctionnement
ENA | Permettre de gérer l’amplitude de la tension délivrée au Moteur A grâce à un signal PWM
IN1&IN2 | Permettent de contrôler le pont en H donc le sens du Moteur_A
ENB | Permettre de gérer l’amplitude de la tension délivrée au Moteur B grâce à un signal PWM
IN3&IN4 | Permettent de contrôler le pont en H par conséquent le sens du Moteur B
Sortie pont A | Pour connecter le Moteur_A
Sortie pont B | Pour connecter le Moteur_B
b. Schéma interne du pont en H

Le schéma du pont en H de la figure 34 est constitué de quatre transistors NPN

fonctionnent en régime de commutation c’est à dire (bloqué ou saturé) ça dépend de l’état

de la base de transistor. Le circuit de commande est composé par les ports AND et

inverseurs qui permettent de contrôler les bases des transistors. Comme il est montré dans

le tableau de vérité ci-dessous.

Figure 34: Schéma électronique de pont en H

Chapitre II : L’étude de régulateur PID et Description de fonctionnement du suiveur de piste

Tableau 3:La Table de vérité de fonctionnement de contrôle d’un moteur

INT1 | INT2 | ENA | Etat T1 | Etat T2 | Etat T3 | Etat T4 | L’état d’un moteur
0 | 0 | 0 | Bloqué | Bloqué | Bloqué | Bloqué | Arrêt
0 | 0 | 1 | Bloqué | Saturé | Bloqué | Saturé | Arrêt
0 | 1 | 0 | Bloqué | Bloqué | Bloqué | Bloqué | Arrêt
0 | 1 | 1 | Bloqué | Bloqué | Saturé | Saturé | Marche en avant
1 | 0 | 0 | Bloqué | Bloqué | Bloqué | Bloqué | Arrêt
1 | 0 | 1 | Saturé | Sature | Bloqué | Bloqué | Marche en arrière
1 | 1 | 0 | Bloqué | Bloqué | Bloqué | Bloqué | Arrêt
1 | 1 | 1 | Saturé | Bloqué | Saturé | Bloqué | Arrêt

De ce tableau qui généralise les différents cas possibles pour commander les quatre

transistors qui permutent le sens de rotation du moteur CC. On résume les cas possibles

dans le tableau récapitulatif ci-dessous :

INT1 | INT2 | ENA | Le sens d’un moteur
0 | 1 | 1 | Avant
1 | 0 | 1 | Arrière
c. Le moteur a courant continue
Les | engrenages | c’est | l’ensemble | des | deux | roues | dentées | s’engrenant
l’une | avec | l’autre | et | permettant | de | transmettre | un | mouvement | ou | une
puissance avec un rapport de vitesse invariable. Leur fonctionnement comme le montre le schème de bloc ci-dessous.

Figure 35: Schéma bloc de fonctionnement des engrenages

La figure 36 montre une coupe d’un motoréducteur qui regroupe un moteur à courant continue et un réducteur à engrenages.

ωm | Les Engrenages | ωS

Chapitre II : L’étude de régulateur PID et Description de fonctionnement du suiveur de piste

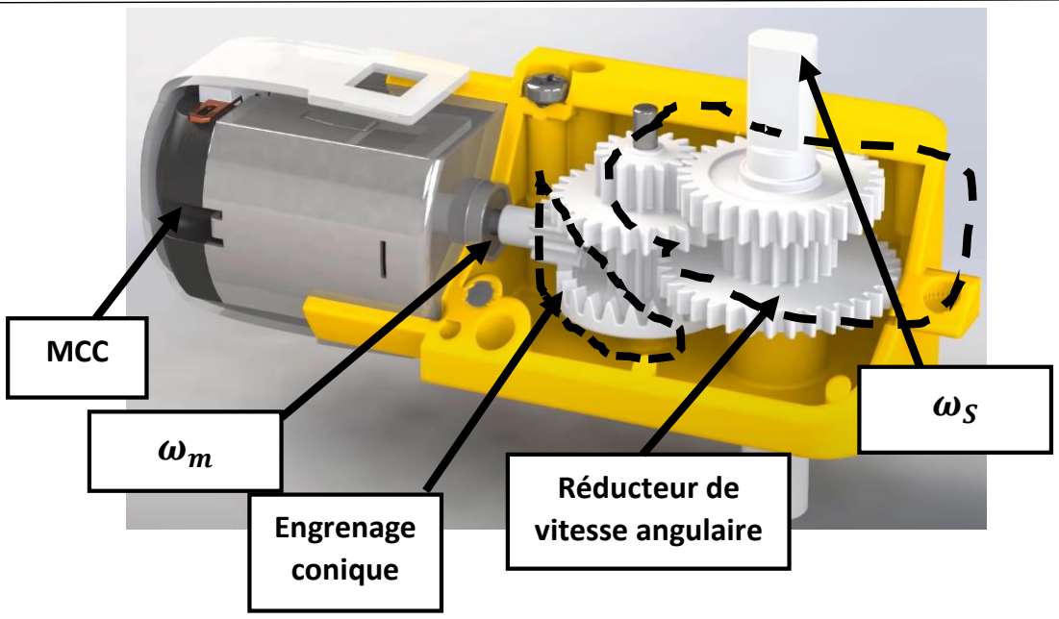
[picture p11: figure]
Réducteur de; Engrenage; vitesse angulaire; conique; MCC

Figure 36: La coupe du moteur Mcc

Le rapport de transmission est donné par la relation suivante :

r : le rapport de transmission.

### Cm,Cs

: sont découples respectivement, moteur et récepteur.
ωs
: La vitesse de rotation angulaire de sortie.

ωm : La vitesse de rotation angulaire de moteur Mcc.

Mcc : moteur à courant continue.

II.2 Appinventor

App Inventor est un outil qui propose aux développeurs d'applications Android une plateforme pour la conception facile des applications Android. Pour cela l’outil propose un code de programmation schématique en déplaçant uniquement des blocs préprogrammés. C’est le langage scratch c’est un langage graphique comme le montre la figure 37.

r =

ωs
ωm

=

Cm
Cs

< 1

Chapitre II : L’étude de régulateur PID et Description de fonctionnement du suiveur de piste

Figure 37: App inventor et langage scratch

Cet outil nous permettra par la suite de réaliser une application Android pour communiquer avec le capteur Bluetooth.

Conclusion
Dans cette partie nous avons étalé le cahier de charge de notre projet et pour sa réalisation nous avons présenté les différents composants qui seront la base pour la réalisation du robot suiveur. Ces composants nécessitent pour leurs utilisations une connaissance profondes et une maitrise parfaite de son fonctionnement ce qui a nécessité beaucoup de temps.

Chapitre III : La réalisation, Conception et Simulation

## Chapitre III : Conception, Simulation et Réalisation

Introduction
Le sujet de notre projet c’est un suiveur de piste avec PID permettant d’amortir les

oscillations et les perturbations au cours du déplacement. Et durant la période de réalisation

de notre projet on a rencontré un certain nombre de problèmes techniques que nous avons

résolus ou bien proposer d’autres alternatives. En cite par exemple le problème causé par

la roue libre qui perturbait le mouvement du robot pour éliminer ce problème nous avons

proposé un robot à quatre roues motrices. Le problème d’une alimentation s’est fortement

posé lors des essais sur piste ce qui nous a poussé à bidouiller une alimentation à piles

rechargeables pour résoudre le problème.

On a développé notre projet afin d’éviter les problèmes mécanique et technique qui

ont influencé sur le système du robot, c’est pour ça notre projet prend beaucoup du temps,

de recherche, de travail et des essais pour optimiser les performances et l’amélioration

d’intelligence de robot.

Ce chapitre entame en premier lieu la partie matérielle qui nous permettra de

comprendre l’usage et le fonctionnement des organes de notre robot. On abordera aussi la

stratégie de fonctionnement qui élabore l’évolution d’erreur des capteurs IR par rapport à

la position de la piste et le régulateur PID qui permet de minimiser l’erreur par la

modification de vitesse des moteurs et de même l’optimisation des performances du robot

suiveur de piste. Et par la suite on va étaler les différents problèmes rencontrés durant la

phase de réalisation et les solutions que nous avons proposé, et enfin une présentation

finale d’un schéma synoptique globale de suiveur de piste avec PID intelligent qui réalise

plusieurs modes.

III.1. Présentation matérielle de robot
Le travail que nous avons réalisé, se compose de deux parties : la partie mécanique

et électronique/programmation.

III.1.1. La partie mécanique
Généralement le robot constitue par deux roues motrices indépendantes qui

permettent d’avancer, de reculer, de tourner à gauche ou à droite. Ainsi que d’une roue

libre permettant de maintenir l’équilibre de robot.

Chapitre III : La réalisation, Conception et Simulation

- Avant montage

Les pièces et matérielle qu’on a besoin pour faire le montage de notre robot.

Deux roues; Châssis; Accessoires de montage; Deux moteurs CC; Roue de guidage; Tournevis

Figure 38: Les pièces de robot

- Après montage

Après avoir assemblé toutes les pièces citées dans la figure 38 à l’aide d’un

tournevis, on obtient notre châssis comme il est présenté dans la figure 39.

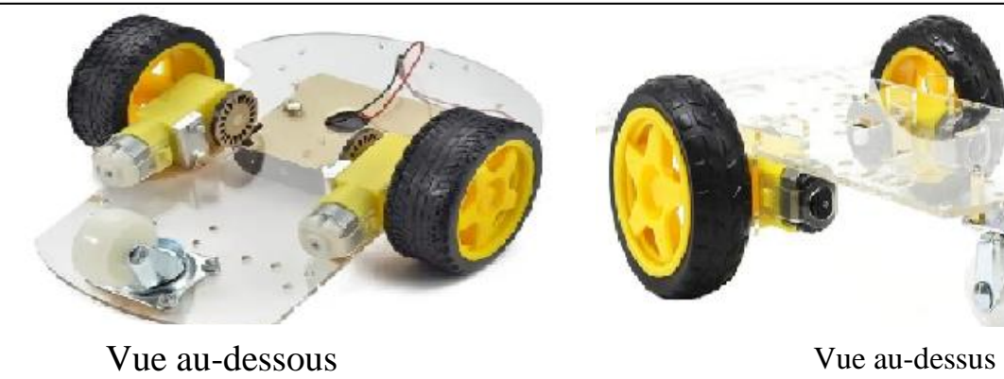
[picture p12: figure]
Vue au-dessous; Vue au-dessus

Figure 39: Le montage de châssis de robot

III.1.2. La partie électronique III.1.2.1. Les cartes électroniques

Pour la partie électronique nous avons utilisé deux cartes électroniques, la première

c’est la carte de commande Arduino Uno et la deuxième est la carte de puissance.

Chapitre III : La réalisation, Conception et Simulation

- La carte Arduino :

Notre carte contient l’algorithme responsable de traiter les informations des

capteurs infrarouge et exécute l’algorithme du régulateur PID que nous avons mis au point

en utilisant IDE Arduino.

- La carte de puissance :

Il s’agit d’un Shield « L298N » qu’on emboîte directement sur notre carte pour

commander nos deux moteurs à courant continu avec la puissance nécessaire et la

possibilité de réglage de la vitesse et du sens de leurs rotations.

Nous montrons sur la figure ci-dessous nos deux cartes électroniques :

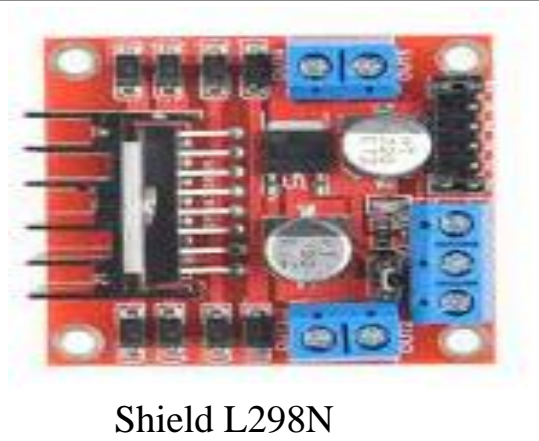
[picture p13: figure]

Figure 40: Les cartes électroniques

III.1.2.1.1. Les capteurs infrarouge tct5000
Le rôle de ces capteurs pour capter une piste noire et ils envoient l’information

logique Tout ou Rien à Arduino Uno, l’image de ce type de capteur cite ci-dessous. Nous

avons utilisé cinq capteurs infrarouge mis côte à côte devant le repos et situés le plus près

du sol pour détecter la piste. En position normale le capteur du milieu doit être positionné

sur la piste les deux de part et d’autre sont placés sur le fond blanc. Le choix de ce nombre

de capteurs permet une meilleur précision et stabilité.

Shield L298N | Arduino Uno

Chapitre III : La réalisation, Conception et Simulation

Figure 41: Capteur infrarouge

La simulation sous Proteus ISIS nous a permis de comprendre le fonctionnement de ce capteur avec la carte Arduino, comme le montre la figure 42.

Figure 42: Simulation sous ISIS du capteur avec un moteur

III.2. Le fonctionnement de suiveur de piste Après avoir écrit le programme sur la plateforme Arduino le robot est positionné

sur la piste comme le montre la figure 43.

Illustration de capteur infrarouge | Les Cinq capteurs de notre robot

Chapitre III : La réalisation, Conception et Simulation

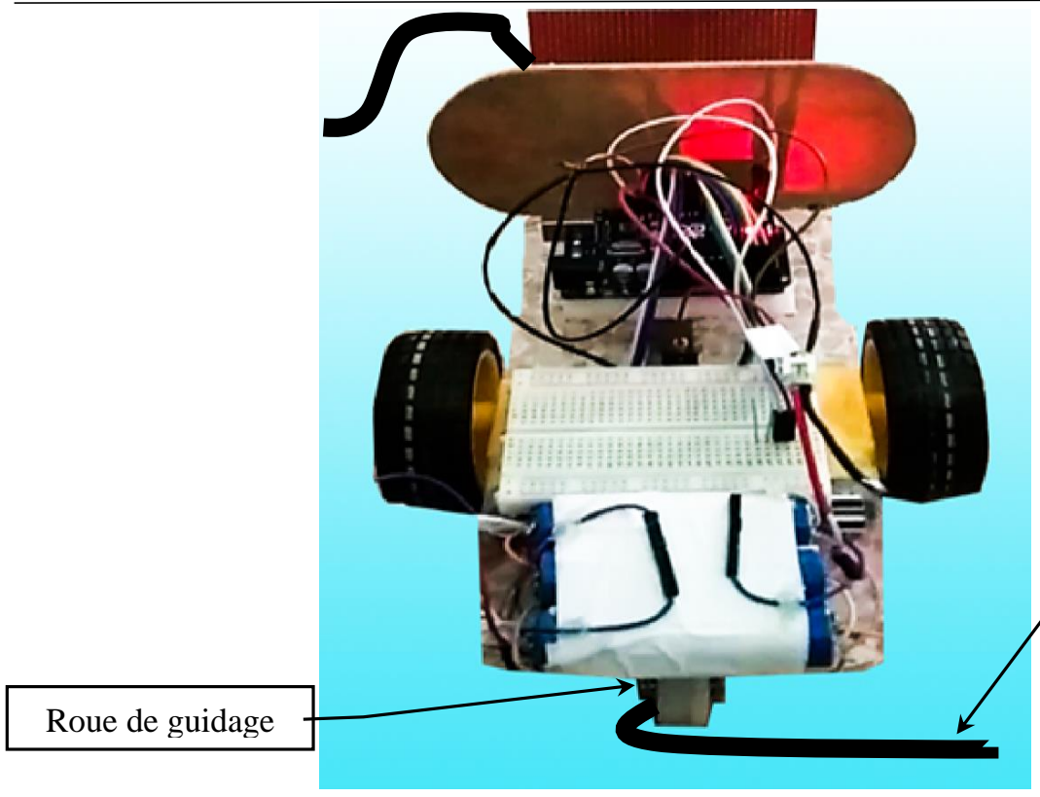
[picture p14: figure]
Roue de guidage

Figure 43: Le robot suiveur de piste

Tout d’abord les Cinq capteurs infrarouge place devant le robot chaque capteur a

une réponse TOR (Tout ou Rien) s’il détecte la piste noir il génère la réponse discrète (1)

sinon il fournit un état (0), le capteur du milieu N

0
2 comme un référence d’erreur, s’il capte

tout seul la piste noir c’est la position normale dans ce cas il n’y a pas d’erreur par contre si les capteurs N⁰

3 ou N⁰
4 captent tous les deux la piste c’est à dire que notre robot diverge

à gauche alors l’unité de traitement donne l’ordre sur les moteurs afin de régler le robot sur la piste, de même pour les capteurs N⁰

0, N⁰
1.

Bref, on distingue deux signes d’erreurs c’est uniquement pour régler la vitesse des

moteurs par l’exécution d’algorithme du régulateur PID qui est traité par (Arduino uno),

Le tableau 5 regroupe et explique brièvement le fonctionnement et les différentes

possibilités du suiveur de piste. Plus on s’écarte de la piste plus l’erreur en valeur absolue

augmente.

La piste

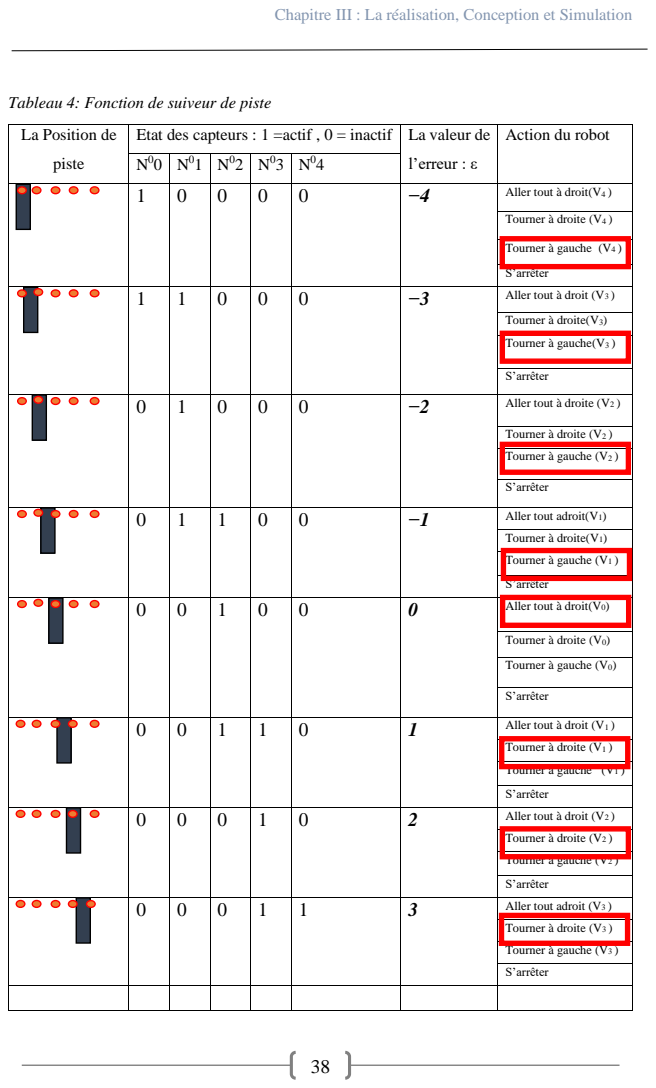
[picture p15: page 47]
Tourner à droite (V4 ); Tourner à gauche (V4 ); S’arrêter; Tourner à droite(V3); Tourner à gauche(V3 ); Tourner à droite (V2 ); Tourner à gauche (V2 ); Tourner à droite(V1); Tourner à gauche (V1 ); Tourner à droite (V0); Tourner à gauche (V0); Tourner à droite (V1 ); Tourner à droite (V3 ); Tourner à gauche (V3 )

Chapitre III : La réalisation, Conception et Simulation

Tableau 4: Fonction de suiveur de piste

La Position de piste | Etat des capteurs : 1 =actif , 0 = inactif | La valeur de l’erreur : ε | Action du robot

0 N 0 | 0 N 1 | 0 N 2 | 0 N 3 | 0 N 4
1 | 0 | 0 | 0 | 0 | −4 | Aller tout à droit(V4 )

Aller tout à droit (V3 )

Aller tout à droite (V2 )

Aller tout adroit(V1)

Aller tout à droit(V0)

Aller tout à droit (V1 )

Aller tout à droit (V2 )

Aller tout adroit (V3 )

Chapitre III : La réalisation, Conception et Simulation

La vitesse des moteurs est modulée en fonction de la valeur PID qui dépende de l’erreur et des

coefficients du régulateur PID qui sont Kp (action P), Ki (action intégrale) et Kd (action

dérivée) déjà traité dans le chapitre II.

Vn : La vitesse réglable par le régulateur numérique PID

V0: La vitesse initiale d’un moteur

Telle que n = {0, 1, 2, 3,4} ce sont des indices des différentes vitesses réglables dépendent

de la position de piste (Tableau 5).

Le régulateur PID dépend de l’erreur et l’erreur change son signe car elle dépende

de la position par rapport à la piste donc la vitesse (Vn) change en fonctionne du signe et

de la valeur d’erreur.

III.3. Les problèmes et solutions

III.3. 1. Les problèmes techniques III.3.1.1. La connexion des capteurs
- Le Problème : la connexion des capteurs infrarouge

Initialement on a connecté les capteurs avec la carte Arduino en utilisant des fils

électriques (figure 44) ce qui introduit de temps à autre des dysfonctionnements de la

réponse du suiveur.

La vitesse de moteur à droite : Vn = V0 + PID

La vitesse de moteur à gauche : Vn = V0 − PID

### V4 > V3 > V2 > V1 > V0

Chapitre III : La réalisation, Conception et Simulation

Figure 44: Le problème de connexion des capteurs infrarouge

- La Solution : carte imprimée pour la connexion des capteurs

La solution optimale qu’on a fait c’est de tracer le circuit dans logiciel TCI après

on a imprime le typon et par suite on a fait l’opération de fabrication de la carte dans

l’atelier de circuit imprime en respectant les conditions et des étapes à suivre (figure 45).

Figure 45: circuit imprimé des capteurs infrarouges

### Les files de connexion

Soudure les capteurs sur la carte de circuit imprime

Le typon | La réalisation du circuit par logiciel TCI

Chapitre III : La réalisation, Conception et Simulation

III.3.2. Installation du robot manuellement sur une piste et réglage des coefficients du régulateur PID à distance.
- Le problème : installation manuellement du robot et réglage des coefficients PID

à distance ce qui va permettre de diminuer le temps des essais et de réglage.

- La solution : commande par Bluetooth via une application et un smartphone.

Le Bluetooth est un système de transmission de données sans fil à courte portée par

liaison radio. Le but initial du Bluetooth est de commander à distance notre robot. Donc

Le module qu’on a utilisé c’est HC-06 : Il permet d'établir une liaison Bluetooth (liaison

série) entre une carte Arduino et le smartphone qui possède une connexion Bluetooth. Le

module HC-06 est un module "esclave".

Ce module Bluetooth va nous permettre aussi de contrôler les coefficients du

régulateur PID dans le programme Arduino Uno.

Figure 46: Application pour contrôler le robot par Bluetooth

On a d’abord créé une application qui va gérer les instructions des boutons de

commande et des coulissiers de niveau pour les coefficients du régulateur App Inventor.

L’algorithme de création de l’application (figure47) est donné sur la figure 48.

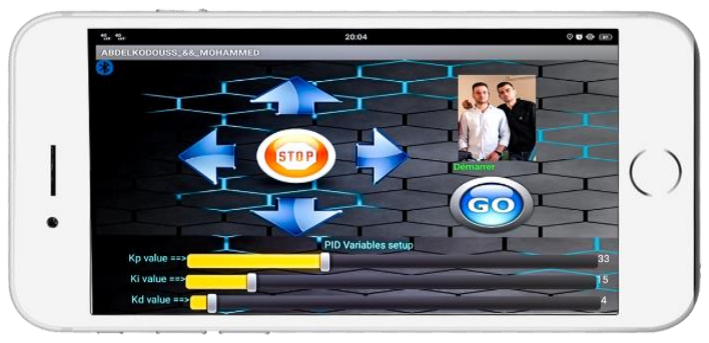
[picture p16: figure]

Figure 47: Aspect de l’application Android réalisée

Chapitre III : La réalisation, Conception et Simulation

Chapitre III : La réalisation, Conception et Simulation

Figure 48: Algorithme de l’application Bluetooth

III.3.2.1. Le robot ne détecte pas l’obstacle sur la piste
- Le problème : détection d’obstacle

Lors de déplacement du robot sur une piste, le suiveur de piste ne détecte pas

l’obstacle.

Figure 49: Le robot ne détecte pas l’obstacle

- La solution : ajouter un capteur qui détecte l’obstacle.

L’élément qui détecte les obstacles qu’on a utilisé c’est un capteur ultrason HC-

Figure 50: Aspect et fonctionnement du capteur ultrason

On a fait des essais pour tester le fonctionnement du capteur et la réaction du robot,

une illustration est donnée sur la figure 51.

Chapitre III : La réalisation, Conception et Simulation

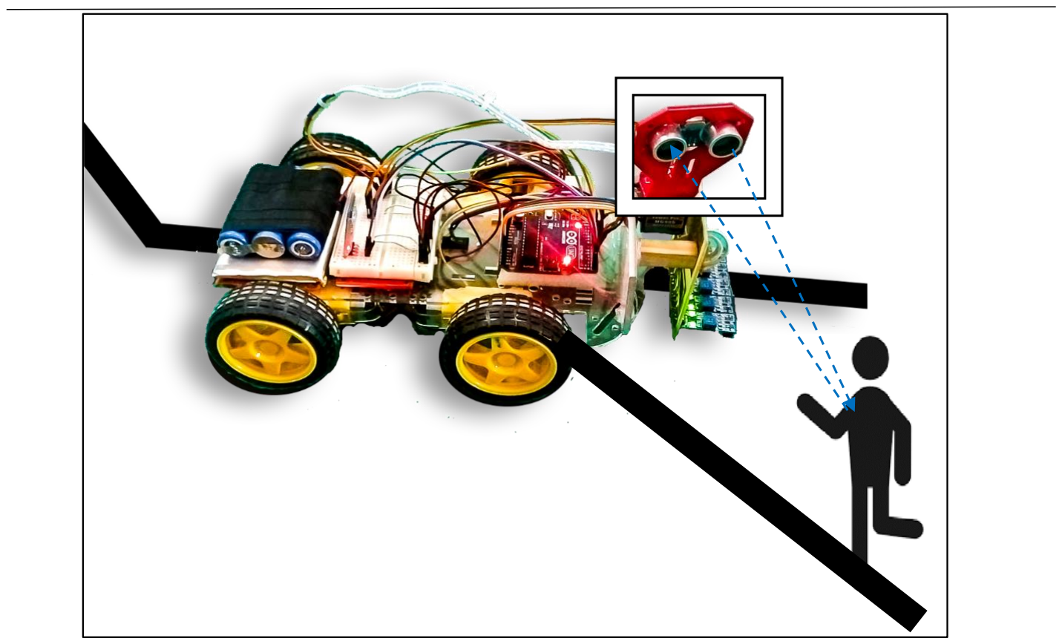
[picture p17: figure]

Figure 51: Illustration de fonctionnement du capteur

III.3.2.2. Le chargeur de batterie lithium
- Le Problème : chargeur spécial de batterie pour alimenter le robot.

Nous avons récupéré trois pilles de lithium de 3,7V chacune (à partir d’une batterie

d’un pc-portable. Mais il reste à réaliser le chargeur adéquat pour charger ces piles.

- La Solution : régulateur de tension

On a conçu un chargeur en assemblant trois régulateurs récupérés des batteries

portables (Power Bank) ce qui permet d’obtenir une tension 3,7V stable et coupe

automatiquement l’alimentation si les piles sont chargées, la structure et le branchement

sont montrés sur la figure 52.

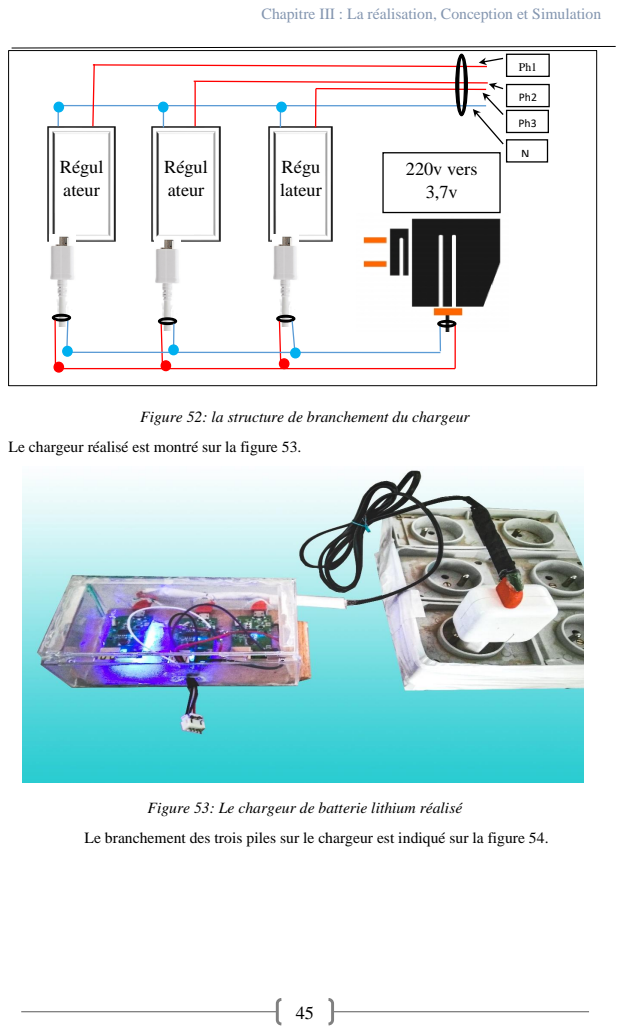
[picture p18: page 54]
Régul ateur; Régu lateur; 220v vers 3,7v

Chapitre III : La réalisation, Conception et Simulation

Figure 52: la structure de branchement du chargeur

Le chargeur réalisé est montré sur la figure 53.

Figure 53: Le chargeur de batterie lithium réalisé

Le branchement des trois piles sur le chargeur est indiqué sur la figure 54.

Chapitre III : La réalisation, Conception et Simulation

Figure 54: La structure de charger des piles

Pour réaliser la batterie du robot nous avons relié les trois piles avec une configuration série ce qui va permettre d’avoir une tension de l’ordre de 11V (figure 55).

Figure 55: La configuration de la batterie réalisée.

III.3.2. Les problèmes mécaniques
III.3.2.1. Roues de guidage : roue décentré orientable et roue à bille
- Le Problème : l’oscillation du robot

Le tableau ci-dessous résume les défauts de roue de guidage causés.

Tableau 5:Les défauts de roue de guidage

Type de robots | Avantages | Inconvénients | Symbole de roue de guidage
Suiveur de piste tricycle à Roue décentré orientable | • Economise la consommation d’énergie | • Instable • Orientation pas précis
Suiveur de piste tricycle à Roue à bille | • Economise la consommation d’énergie | • Glissement non roulement (frottement)
- La Solution : utilisation deux roues motrices

Chapitre III : La réalisation, Conception et Simulation

Type de robot | Avantages | Inconvénients | Symbole des roues de guidage
Suiveur de piste à quatre roues motrices | • Stable • La réponse précise | • Consomme l’énergie

Donc pour éliminer les oscillations et perturbations causées par la roue libre nous l’avons

remplacé par deux roues motrices, donc aux finales nous avons utilisé quatre roues motrices

commandées deux par deux c’est-à-dire que la roue de devant et la roue d’arrière

correspondante sont commandées en parallèle. Ce qui permet une très bonne stabilité du robot.

III.3.2.2. La vitesse des quatre moteurs n’est pas identique

- Le problème : la vitesse du moteur à gauche différent de celle du moteur à droite

Au départ des tests le fonctionnement de notre robot sur une piste noire, on a

constaté un déséquilibre du fonctionnement du robot, ce problème nous a pris beaucoup de

temps pour le résoudre.

- La Solution : réglage la vitesse expérimentalement

En faisant plusieurs essais on a diminué la vitesse des moteurs à gauches pas à pas

jusqu’à l’équilibre du robot. Le but de cette expérience c’est d’éliminer l’offset de la

vitesse des moteurs à gauche.

III.4. Le Schéma global de suiveur de piste avec PID intelligent
Le schéma synoptique du suiveur de piste que nous avons réalisé est représenté sur

la figure 56, il fait ressortir les différents composants qui constituent le projet ainsi que

leurs interconnexions.

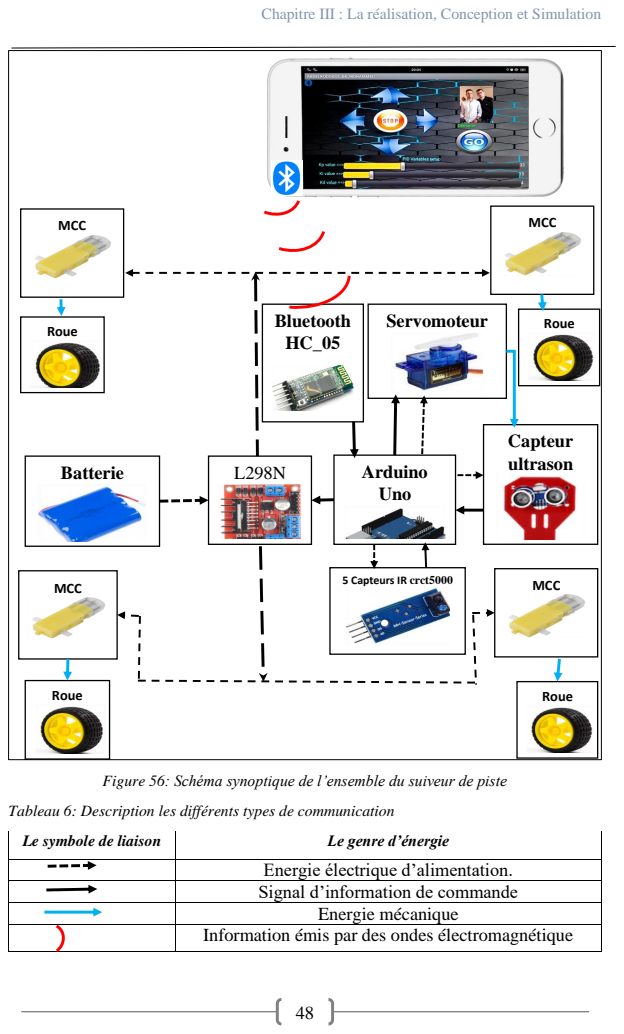
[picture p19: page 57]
Le symbole de liaison; Le genre d’énergie; Batterie; Servomoteur; Capteur ultrason Arduino; Uno; MCC; 5 Capteurs IR crct5000; Bluetooth HC_05; Roue

Chapitre III : La réalisation, Conception et Simulation

Figure 56: Schéma synoptique de l’ensemble du suiveur de piste

Tableau 6: Description les différents types de communication

Energie électrique d’alimentation.
Signal d’information de commande

Energie mécanique

Information émis par des ondes électromagnétique

Chapitre III : La réalisation, Conception et Simulation

Pour rappel, la structure globale du robot suiveur de piste ainsi que ses interfaces

de commandes, sont présentées ci-dessus :

- La batterie génère 11,1v, qui permet d’alimenter directement le module L298N.
- Le module Bluetooth permet la communication entre le Smartphone et le suiveur

de piste.

- Le capteur ultrason permet au robot d’éviter les obstacles.
- Les capteurs infrarouges, situés sous le robot, assurent le suivi d’une piste noir

continue.

- Le servomoteur permet au capteur ultrason de baliser la zone dans laquelle le

robot évolue.

- Les moteurs à courant continu (MCC) permettent le déplacement du robot.
- Le module L298N permet de contrôler le sens de rotation et la vitesse des

moteurs (MCC).

- La carte Arduino Uno est l’élément qui fait le traitement et le contrôle des

données, et elle joue le rôle de distributeur d’énergie aux différents éléments de

robot.

III.5. La connexion entre les composants de suiveur de piste avec PID intelligent

Le montage de la figure 57, réalisé sous le logiciel Fritzing, montre les différents

éléments du suiveur et leurs connections.

Chapitre III : La réalisation, Conception et Simulation

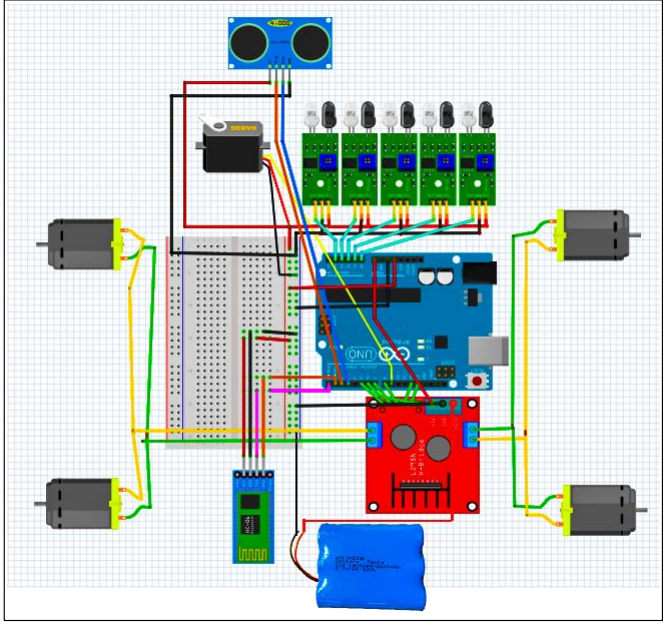
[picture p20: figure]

Figure 57: Le branchement des composants du robot par logiciel Fritzing

Les branchements de chaque composant sont regroupés dans les tableaux de 8 à 12.

Tableau 7:Les capteurs infrarouges IR

Tableau 8:Les broches de capteur ultrason :

Tableau 9:Les broches de capteur ultrason :

Numéro des capteurs de pine {D0} | Les pines d’Arduino
N⁰ O de | A0
N⁰ 1 | A1
N⁰ 2 | A2
N⁰ 3 | A3
N⁰ 4 | A4
Capteur | Arduino
Trigger | 2
Écho | 3_pwm
Servomoteur | Arduino
Pulse signal | 9

Chapitre III : La réalisation, Conception et Simulation

Tableau 10:Les broches de carte Bluetooth

Carte Bluetooth | Arduino
TX | RX
RX | TX

Les broches des moteurs :

Les deux moteurs à droite sont en parallèle, de même manière pour les moteurs à gauche.

Les moteurs à gauche sont branchés dans le pont A et les moteurs à droite sur le pont B du

module driver moteur.

Tableau 11:La connexion entre Arduino et driver moteur du pont H

Arduino | Driver moteur
Les pines | Moteurs à gauche | Moteurs à droite
5pwm | Χ | ENB
7 | Χ | IN4
8 | Χ | IN3
6pwm | ENA | Χ
13 | IN1 | Χ
12 | IN2 | Χ

Chapitre III : La réalisation, Conception et Simulation

III.6. Localisation des composants sur le robot suiveur de piste

Figure 58: Vue au-dessous de robot

Figure 59:Vue au-dessus de robot

Deux
roues

Deux roues
motrices à
gouache

Cinque
capteurs
infrarouge

Contrôle des
moteurs(L298N)

Moteur CC

La batterie Carte Bluetooth

Les capteurs IR

Arduino Uno | Le capteur ultrason

Servomoteur

Chapitre III : La réalisation, Conception et Simulation

III.7. Les modes de suiveur de piste avec PID intelligent

On a ajouté des modes pour donner à notre robot la fonction de multitâches, comme

le schématise la figure 60. Les tâches sont décrites dans le tableau 12.

Figure 60: Les multitâches de robot

Tableau 12: Description de différentes tâches de robot

Les tâches | Le fonctionnement de robot | Le but | La structure de commande
Tache 1 | Suiveur de piste avec PID. | Le robot suit une piste. | Automatique
Tache 2 | Suiveur de piste avec PID commande par smartphone. | Le robot suit une piste mais on peut changer sa direction pour le déplacer dans une autre piste. | Semi maître-esclave
Tache 3 | Détecteur l’obstacle dans un environnement | Le robot détecte l’obstacle et le contourne et continue son trajet. | Automatique

Chapitre III : La réalisation, Conception et Simulation

Tache 4 | Détecteur l’obstacle dans un environnement et contrôle par le smartphone. | Le robot contourne les obstacles et il est orientable à distance. | Semi maître-esclave
Tache 5 | Piloter par un smartphone. | Le robot est guidé à distance. | Maître-esclave

### Conclusion

Dans ce chapitre nous avons explicité les différentes étapes et câblage des

composants qui nous ont permis de réaliser le robot suiveur de piste. Nous avons aussi

évoqué les problèmes techniques rencontrés et les solutions que nous avons proposées.

Nous avons doté notre d’un certains nombres de capteurs qui lui permettent un

fonctionnement multitâche.

## Conclusion générale

Ce projet de fin d’étude est le résultat d’un travail de recherche dans le domaine de

la robotique et l’automatique. Il est consacré à la commande d’un robot mobile à distance

avec évitement d’obstacles automatique basé sur une carte Arduino UNO, cinq capteurs

infrarouges lui indiquant sont emplacement par rapport la piste, il est aussi doté d’un

capteur à ultrason comme moyen de perception et permet au robot de contourner les

obstacles, quatre roues motrices entrainées par des moteurs à courant continu commandés

par un driver de puissance basé sur le pont H double L298N. Un module HC-06 permettant

d’avoir une liaison Bluetooth afin de pouvoir télécommander à distance le robot par une

application Android que nous avons développée par l’intermédiaire de la plateforme App

Inventor.

Pour aboutir à cela nous avons partagé le travail en deux étapes. La conception du

robot mobile, ou nous avons étudié les spécifications des différents composants utilisés et

étudier leurs caractéristiques et leur fonctionnement. La réalisation, où nous avons donné

les étapes à suivre pour construire le robot.

Notre projet permet la possibilité d’amélioration les performances du suiveur de

piste à distance, car une fois le robot est opérationnel on peut modifier son algorithme de

PID par le mode Bluetooth et la possibilité de plusieurs tâches.

Ce projet nous a apporté énormément d’informations et d’enseignement dans plusieurs

domaines mécanique, électronique, informatique et automatique. Ce qui nous a permis d’élargir

nos connaissances dans ces domaines.

## Annexe

- Les organigrammes du programme de suiveur de ligne :
1) Organigramme du programme principal :

### 2) Organigramme du programme de connexion Bluetooth :

### 3) Organigramme du programme de choix des modes :

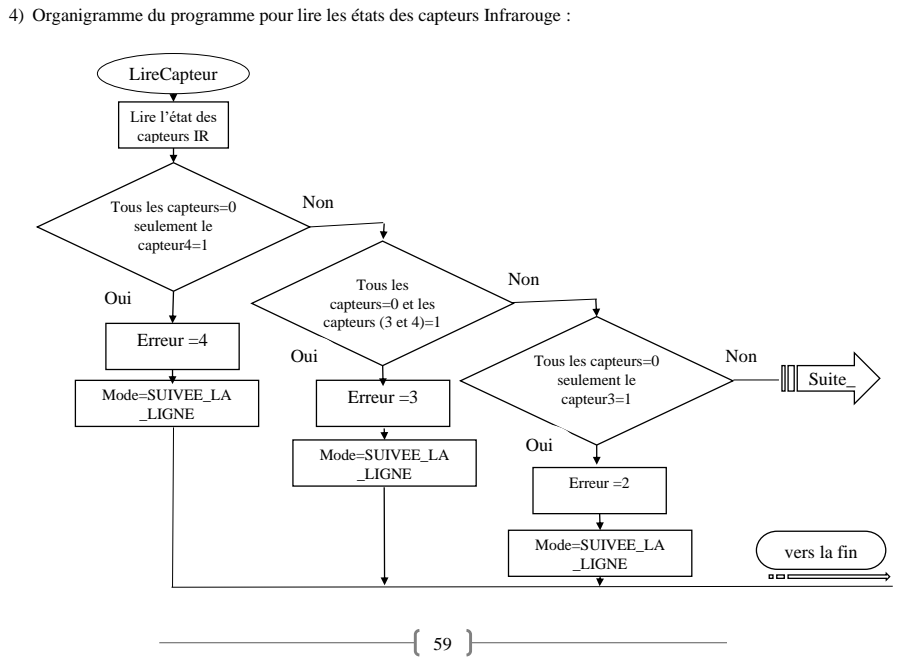
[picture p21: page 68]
Tous les capteurs=0; Non; seulement le capteur4=1; Erreur =4; Mode=SUIVEE_LA _LIGNE; Erreur =3; Oui; Erreur =2; Suite_; LireCapteur

4) Organigramme du programme pour lire les états des capteurs Infrarouge :

Lire l’état des
capteurs IR

Tous les
capteurs=0 et les
capteurs (3 et 4)=1

Tous les capteurs=0
seulement le
capteur3=1

vers la fin

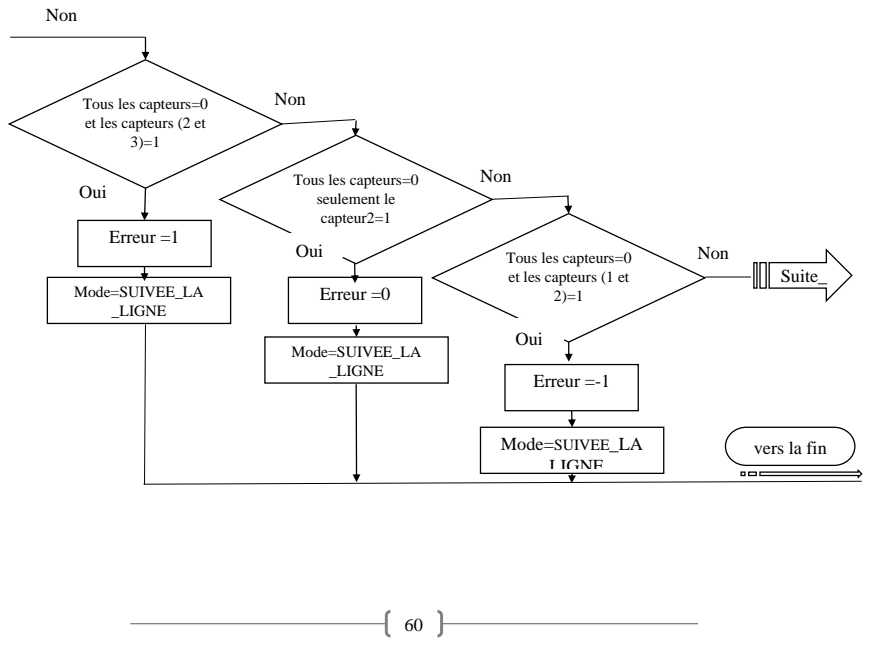
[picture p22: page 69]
Tous les capteurs=0; Non; Erreur =1; Mode=SUIVEE_LA _LIGNE; Erreur =0; Oui; Erreur =-1; Suite_

et les capteurs (2 et

Tous les capteurs=0
seulement le
capteur2=1

et les capteurs (1 et

vers la fin

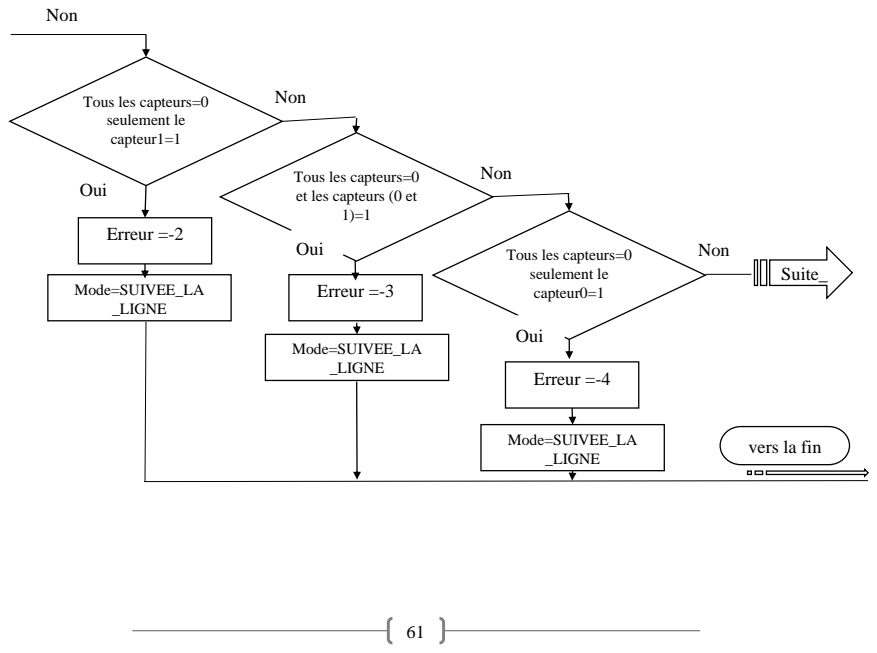
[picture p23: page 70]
Tous les capteurs=0; Non; seulement le capteur1=1; Erreur =-2; Mode=SUIVEE_LA _LIGNE; Erreur =-3; Oui; Erreur =-4; Mode=SUIVEE_LA; _LIGNE; vers la fin; Suite_

Tous les capteurs=0
et les capteurs (0 et

seulement le
capteur0=1

### 5) Mode Suiveur de ligne avec PID

Vitesse du moteur à gauche = vitesse initiale

Vitesse du moteur à droite = vitesse initiale -

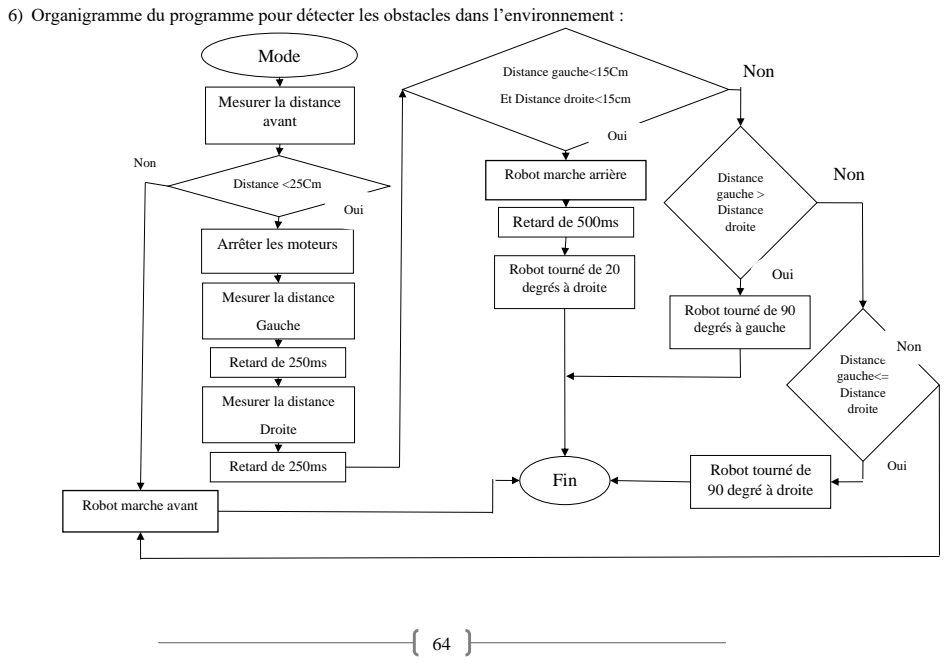
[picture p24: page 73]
Mode; avant; Distance <25Cm; Gauche; Retard de 250ms; Droite; Fin; Non; Distance gauche<15Cm; Retard de 500ms; Distance gauche > Distance droite; Distance gauche<= Distance droite; Oui

6) Organigramme du programme pour détecter les obstacles dans l’environnement :

Et Distance droite<15cm

Mesurer la distance

Robot marche arrière

Arrêter les moteurs

Robot tourné de 20
degrés à droite

Robot tourné de 90
degrés à gauche

Robot tourné de
90 degré à droite

Robot marche avant

Webographie

### - http://www.isetn.rnu.tn/archives/fr/index.php?id=41

### - https://www.positron-libre.com/electronique/arduino/arduino.php

### - http://fabrice.sincere.pagesperso-orange.fr/gestion_projet.htm

### - http://profge.free.fr/cours.html

### - https://sites.google.com/site/stetanger/2ste/cours

### - https://fr.calameo.com/read/003183492b504ba8cf987

### - https://www.enib.fr/~kerhoas/asserv_mcc_correcteur.html

### - http://prive.iutenligne.net/ghLxeOc3vnR15NUq/automatique-et-

automatismes-industriels/konn/asnum/numA/index.html (http://prive.iutenligne.net/ghLxeOc3vnR15NUq/automatique-et-automatismes-industriels/konn/asnum/numA/index.html)

### - https://www.tubefr.com/linusbot-robot-suiveur-de-ligne.html

### - https://www.memoireonline.com/01/19/10544/Realisation-d-un-robot-

mobile-avec-evitement-d-obstacle-et-trajectoire-programmee.html (https://www.memoireonline.com/01/19/10544/Realisation-d-un-robot-mobile-avec-evitement-d-obstacle-et-trajectoire-programmee.html)

### - https://www.electronique-mixte.fr/projet-electronique-18-wattmetre-avec-

arduino/ (https://www.electronique-mixte.fr/projet-electronique-18-wattmetre-avec-arduino/)

### - http://maximefarin.weebly.com/robot-eacuteviteur-dobstacles.html

### - http://users.polytech.unice.fr/~pmasson/Enseignement-arduino.htm

### - https://ardwinner.jimdofree.com/arduino/ix-les-modules-de-

communication-bluetooth/ (https://ardwinner.jimdofree.com/arduino/ix-les-modules-de-communication-bluetooth/)

### - http://tpil.projet.free.fr/2017/robot1.h

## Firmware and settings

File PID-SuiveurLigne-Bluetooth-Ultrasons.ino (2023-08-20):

 /*********************************************************************************************
                                        INIAILISATION
**********************************************************************************************/
#include <Servo.h>
#include <SoftwareSerial.h>

// DECLARATION DES VARIABLE EN LIEN AVEC LE CHOIX DU MODE........................................
# define ARRETE 0
# define SUIVEE_LA_LIGNE 1
# define PAS_DE_LIGNE 2
# define ULTRASONS 3
  int mode = 0;

//DECLARATION EN LIEN AVEC LES MOTEURS...........................................................
   int motor_left_pwmPin  = 6;
   int motor_right_pwmPin = 5;

   int motor_left_pin_1 = 12;
   int motor_left_pin_2 = 13;
   int motor_right_pin_1 = 8;
   int motor_right_pin_2 = 7;
   
   const int power = 180;
   int power_right=200;
   int power_left=140;
/*POUR LE SENSE DES MOTEURS*/
 #define RIGHT 1
 #define LEFT -1

//DECLARATION EN LIEN AVEC LE CAPTEUR DE DISTANCE ET LE SERVOMOTEUR...............................
/*servo moteur*/
  Servo servo;
/* capteur Ulrasons*/
   const int triggerPin=2;//fil orange
   const int echoPin=3;//fil jaune
   const int delay_time = 250;//Temps accordé au servo pour la mesure de la distance de chaque côté
   long duree;
   int distance;
   float intervalle;
   int distanceAvant;
   int distanceDroite;
   int distanceGauche;

//DECLARATION EN LIEN AVEC LES CAPTEURS DE LUMINOSITE..............................................
// LFSensor Le Capteur plus à droit est "0"
   const int lineFollowSensor0 = A0; 
   const int lineFollowSensor1 = A1; 
   const int lineFollowSensor2 = A2; 
   const int lineFollowSensor3 = A3;
   const int lineFollowSensor4 = A4;

   int LFSensor[5]={0, 0, 0, 0, 0};

// Module bluetooth................................................................................
SoftwareSerial BT1(0,1); //le pin 0 à Rx  et  le pin 1 à Tx
String command;
String device;

// PID controller..................................................................................
float Kp=20;
float Ki=12;
float Kd=4;
float error=0, P=0, I=0, D=0, PIDvalue=0;
float previousError=0, previousI=0;

//-------------------------------------------------------------------------------------------------
//-------------------------------------------------------------------------------------------------
void setup() 
{
  //Inialistion de la communication série
  Serial.begin(9600);
  BT1.begin(9600);

  //Inialistion des broches des moteurs
  pinMode(motor_left_pin_1, OUTPUT);
  pinMode(motor_left_pin_2, OUTPUT);
  pinMode(motor_right_pin_1, OUTPUT);
  pinMode(motor_right_pin_2, OUTPUT);
  digitalWrite(motor_left_pin_1,LOW);
  digitalWrite(motor_left_pin_2,LOW);
  digitalWrite(motor_right_pin_1,LOW);
  digitalWrite(motor_right_pin_2,LOW);

 //Inialistion du capteur de distance et du servomoteur 
  pinMode(triggerPin,OUTPUT);
  pinMode( echoPin,INPUT);
  servo.attach(9);//Associe l'objet servo à la pin 9 (PWM)
  servo.write(90); 

  //Inialistion des capteurs de coleur
  pinMode(lineFollowSensor0, INPUT);
  pinMode(lineFollowSensor1, INPUT);
  pinMode(lineFollowSensor2, INPUT);
  pinMode(lineFollowSensor3, INPUT);
  pinMode(lineFollowSensor4, INPUT);
  
  BT1.print("Vérifier les constantes PID à envoyer au Robot");
  BT1.println('\n');
    while (!mode)
  {  
    commande_BT_Serie();
  }
  checkPIDvalues();
}
/***********************************************************************************
                               FONCTION POUR LES MOTEURS
************************************************************************************/
void farword_Right(){
  digitalWrite(motor_right_pin_1, LOW);
  digitalWrite(motor_right_pin_2, HIGH);
 }
 void Backword_Right(){
  digitalWrite(motor_right_pin_1, HIGH);
  digitalWrite(motor_right_pin_2, LOW);
 }
 void farword_Left(){
  digitalWrite(motor_left_pin_1, LOW);
  digitalWrite(motor_left_pin_2, HIGH);
  }
  void Backword_Left(){
  digitalWrite(motor_left_pin_1, HIGH);
  digitalWrite(motor_left_pin_2, LOW);
 }
 void motorStop()
{
  analogWrite(motor_right_pwmPin,0);
  analogWrite(motor_left_pwmPin, 0);
  digitalWrite(motor_right_pin_1, LOW);
  digitalWrite(motor_right_pin_2, LOW);
  digitalWrite(motor_left_pin_1, LOW);
  digitalWrite(motor_left_pin_2, LOW);
  delay(200);
}
//--------------------------------------------- 
void motorForward()
{analogWrite(motor_right_pwmPin,power );
  analogWrite(motor_left_pwmPin, power );
  farword_Right();
  farword_Left();
}
//---------------------------------------------
void motorBackward()
{
   analogWrite(motor_right_pwmPin,power );
  analogWrite(motor_left_pwmPin, power );
  Backword_Right();
  Backword_Left();
}
//---------------------------------------------
void motorTurn(int direction, int degrees)
{
  analogWrite(motor_right_pwmPin,200 );
  analogWrite(motor_left_pwmPin,140 );
if(direction==RIGHT){
  farword_Left();
  Backword_Right();
  delay (round(8*degrees+1));
  motorStop();
}
else if(direction==LEFT){
  farword_Right();
  Backword_Left();
  delay (round(8*degrees+1));
  motorStop();
  }
  }
/************************************************************************************************
                                 FONCTIONS POUR LE MODE ULTRATION
*************************************************************************************************/
void mesurerDistanceAvant()
{
  servo.write(90);
  delay(delay_time);
  digitalWrite(triggerPin, LOW);
  delayMicroseconds(2);
  digitalWrite(triggerPin, HIGH); //Envoie d'une onde sonore
  delayMicroseconds(10);
  digitalWrite(triggerPin, LOW);
  intervalle = pulseIn(echoPin, HIGH); //Réception de l'écho
  intervalle = intervalle/5.8/10; //Conversion de la différence de temps entre l'envoie de l'onde sonore et la réception de l'écho en distance (cm)
  Serial.println("Distance avant:");
  Serial.println(intervalle);
  distanceAvant = intervalle; //Arrondissement de la distance
}
//------------------------------------------------------------------
void mesurerDistanceGauche()
{
  servo.write(180);
  delay(delay_time);
  digitalWrite(triggerPin, LOW);
  delayMicroseconds( 2);
  digitalWrite(triggerPin, HIGH); //Envoie d'une onde sonore
  delayMicroseconds( 10);
  digitalWrite(triggerPin, LOW);
  intervalle = pulseIn(echoPin, HIGH); //Réception de l'écho
  intervalle = intervalle/5.8/10; //Conversion de la différence de temps entre l'envoie de l'onde sonore et la réception de l'écho en distance (cm)
  Serial.println("Distance gauche:");
  Serial.println(intervalle);
  distanceGauche = intervalle;
}
//-------------------------------------------------------------------
void mesurerDistanceDroite()
{
  servo.write(0);
  delay(delay_time);
  digitalWrite(triggerPin, LOW);
  delayMicroseconds( 2);
  digitalWrite(triggerPin, HIGH); //Envoie d'une onde sonore
  delayMicroseconds( 10);
  digitalWrite(triggerPin, LOW);
  intervalle = pulseIn(echoPin, HIGH); //Réception de l'écho
  intervalle = intervalle/5.8/10; //Conversion de la différence de temps entre l'envoie de l'onde sonore et la réception de l'écho en distance (cm)
  Serial.println("Distance droite:");
  Serial.println(intervalle);
  distanceDroite = intervalle;
}
//-------------------------------------------------------------------
void modeUltrason()
{
  mesurerDistanceAvant();  
  if(distanceAvant < 25) //Si la distance avant est de moins de 25cm
  {
    motorStop();
    mesurerDistanceGauche();
    delay(delay_time);
    mesurerDistanceDroite();
    delay(delay_time);
    
    if(distanceGauche < 15 && distanceDroite < 15) //Si la distance à gauche et la distance à droite sont de moins de 15cm
    {
      motorBackward();
      delay(500);
      motorTurn(RIGHT,20);
    }
    else if(distanceGauche > distanceDroite) //Si la distance gauche est plus grande que la distance droite
    {
      motorTurn(LEFT,60);
    }
    else if(distanceGauche <= distanceDroite) //Si la distance gauche est plus petite ou égale à la distance droite
    {
      motorTurn(RIGHT,70);
    }
  }
  else //Si la distance avant est de plus de 25cm
  {
    motorForward();
  }
}
//------------------------------------------------------------------
void ultrasonDistance()
 {
digitalWrite(triggerPin,HIGH);
delayMicroseconds(10);
digitalWrite(triggerPin,LOW);
duree = pulseIn(echoPin,HIGH);
duree = duree/2;
distance = (duree*340)/10000.0;
 }
/***********************************************************************************************
                               FONCTIONS POUR les CAPTEURS INFRAROUGE
************************************************************************************************/
      /* Lire les valeur des capteur de ligne 

                TableCapteur  ValeurError
                 0 0 0 0 1       4              
                 0 0 0 1 1       3              
                 0 0 0 1 0       2              
                 0 0 1 1 0       1              
                 0 0 1 0 0       0              
                 0 1 1 0 0      -1              
                 0 1 0 0 0      -2              
                 1 1 0 0 0      -3              
                 1 0 0 0 0      -4              

                 1 1 1 1 1        0 Robot trouvé ligne continue : ARRETE
                 0 0 0 0 0        0 Robot n'a trouvé aucune ligne : Tourner 180o

      */
void readLFSsensors()
{
  LFSensor[0] = digitalRead(lineFollowSensor0);
  LFSensor[1] = digitalRead(lineFollowSensor1);
  LFSensor[2] = digitalRead(lineFollowSensor2);
  LFSensor[3] = digitalRead(lineFollowSensor3);
  LFSensor[4] = digitalRead(lineFollowSensor4);
  
  if((     LFSensor[0]== 0 )&&(LFSensor[1]== 0 )&&(LFSensor[2]== 0 )&&(LFSensor[3]== 0 )&&(LFSensor[4]== 1 ))  {mode = SUIVEE_LA_LIGNE; error = 4;}
  else if((LFSensor[0]== 0 )&&(LFSensor[1]== 0 )&&(LFSensor[2]== 0 )&&(LFSensor[3]== 1 )&&(LFSensor[4]== 1 ))  {mode = SUIVEE_LA_LIGNE; error = 3;}
  else if((LFSensor[0]== 0 )&&(LFSensor[1]== 0 )&&(LFSensor[2]== 0 )&&(LFSensor[3]== 1 )&&(LFSensor[4]== 0 ))  {mode = SUIVEE_LA_LIGNE; error = 2;}
  else if((LFSensor[0]== 0 )&&(LFSensor[1]== 0 )&&(LFSensor[2]== 1 )&&(LFSensor[3]== 1 )&&(LFSensor[4]== 0 ))  {mode = SUIVEE_LA_LIGNE; error = 1;}
  else if((LFSensor[0]== 0 )&&(LFSensor[1]== 0 )&&(LFSensor[2]== 1 )&&(LFSensor[3]== 0 )&&(LFSensor[4]== 0 ))  {mode = SUIVEE_LA_LIGNE; error = 0;}
  else if((LFSensor[0]== 0 )&&(LFSensor[1]== 1 )&&(LFSensor[2]== 1 )&&(LFSensor[3]== 0 )&&(LFSensor[4]== 0 ))  {mode = SUIVEE_LA_LIGNE; error =- 1;}
  else if((LFSensor[0]== 0 )&&(LFSensor[1]== 1 )&&(LFSensor[2]== 0 )&&(LFSensor[3]== 0 )&&(LFSensor[4]== 0 ))  {mode = SUIVEE_LA_LIGNE; error = -2;}
  else if((LFSensor[0]== 1 )&&(LFSensor[1]== 1 )&&(LFSensor[2]== 0 )&&(LFSensor[3]== 0 )&&(LFSensor[4]== 0 ))  {mode = SUIVEE_LA_LIGNE; error = -3;}
  else if((LFSensor[0]== 1 )&&(LFSensor[1]== 0 )&&(LFSensor[2]== 0 )&&(LFSensor[3]== 0 )&&(LFSensor[4]== 0 ))  {mode = SUIVEE_LA_LIGNE; error = -4;}
  else if((LFSensor[0]== 1 )&&(LFSensor[1]== 1 )&&(LFSensor[2]== 1 )&&(LFSensor[3]== 1 )&&(LFSensor[4]== 1 ))  {mode = ARRETE; error = 0;}
  else if((LFSensor[0]== 0 )&&(LFSensor[1]== 0 )&&(LFSensor[2]== 0 )&&(LFSensor[3]== 0 )&&(LFSensor[4]== 0 ))  {mode = PAS_DE_LIGNE; error = 0;}
}

/************************************************************************************************
                                     CONNEXION PAR BLUETOOTH
*************************************************************************************************/
 void checkBTcmd()  
 { 
   while (BT1.available())   //Vérifier s'il y a un octet disponible à lire
   {
     delay(10); //Retard ajouté pour rendre la chose stable
     char c = BT1.read(); //Effectuer une lecture en série
     device += c; //construire la chaine
   }  
   if (device.length() > 0) 
   {
     Serial.print("Commande reçue BT ==> ");
     Serial.println(device); 
     command = device;
     device ="";  //Réinitialiser la variable
     BT1.flush();
    } 
}
//-----------------------------------------------------
void manualCmd()
{
  switch (command[0])
  {
    case 'g':
      mode = SUIVEE_LA_LIGNE;
      break;
    
    case 's': 
      motorStop(); //Eteindre les deux moteurs
      break;

    case 'f':  
      motorForward();  
      break;

    case 'r':     
      motorTurn(RIGHT, 30);
      motorStop();
      
      break;

   case 'l': 
      motorTurn(LEFT, 30);
      motorStop();
      break;

    case 'b':  
      motorBackward();
      break;

    case 'U':
      mode = ULTRASONS;
      break;
      
    case 'p':
      Kp = command[2];
      break;
    
    case 'i':
      Ki = command[2];
      break; 
    
    case 'd':
      Kd = command[2];
      break;
  }
}
//-------------------------------------------------------
void commande_BT_Serie(){
  checkBTcmd();
  manualCmd();
  command = "";
}

/************************************************************************************************
                                    FONCTIONS POUR PID 
*************************************************************************************************/
void calculatePID()
{
  P = error;
  I = I + error;
  D = error-previousError;
  PIDvalue = (Kp*P) + (Ki*I) + (Kd*D);
  previousError = error;
}
//-----------------------------------------------
void checkPIDvalues()
{
  
  BT1.print("PID: ");
  BT1.print(Kp);
  BT1.print(" - ");
  BT1.print(Ki);
  BT1.print(" - ");
  BT1.println(Kd);  
  
  Serial.print("PID: ");
  Serial.print(Kp);
  Serial.print(" - ");
  Serial.print(Ki);
  Serial.print(" - ");
  Serial.println(Kd);  
  
}
//-----------------------------------------------
void test_Capteurs_SuiviLigne()
{
     int LFS0 = digitalRead(lineFollowSensor0);
     int LFS1 = digitalRead(lineFollowSensor1);
     int LFS2 = digitalRead(lineFollowSensor2);
     int LFS3 = digitalRead(lineFollowSensor3);
     int LFS4 = digitalRead(lineFollowSensor4);
     
     Serial.print ("LFS: L  0 1 2 3 4  R ==> "); 
     Serial.print (LFS0); 
     Serial.print (" ");
     Serial.print (LFS1); 
     Serial.print (" ");
     Serial.print (LFS2); 
     Serial.print (" ");
     Serial.print (LFS3); 
     Serial.print (" ");
     Serial.print (LFS4); 
     Serial.print ("  ==> ");
    
     Serial.print (" P: ");
     Serial.print (P);
     Serial.print (" I: ");
     Serial.print (I);
     Serial.print (" D: ");
     Serial.print (D);
     Serial.print (" PID: ");
     Serial.println (PIDvalue);
}
//--------------------------------------------
void motorPIDcontrol()
{
  int leftMotorSpeed = power - PIDvalue;
  int rightMotorSpeed = power+ PIDvalue;
  
  // La vitesse du moteur ne doit pas dépasser la valeur max PWM
   constrain(leftMotorSpeed, 0, 255);
   constrain(rightMotorSpeed, 0, 255);
  
  analogWrite(motor_right_pwmPin, rightMotorSpeed);
  analogWrite(motor_left_pwmPin, leftMotorSpeed);
   farword_Right();
   farword_Left();
}
//-------------------------------------------------------------------
void Suiveurligne_Ultrasons()
{
 readLFSsensors();
 ultrasonDistance();    
 if(distance <= 20){
  motorStop();
  servo.write(180);
  delay(400);
 }
else{ 
      calculatePID();
      motorPIDcontrol(); 
    servo.write(90);
   }
}
/********************************************************************************************************
                                   Intelligent_Robot_Suiveur_ligne
********************************************************************************************************/

void loop() 
{
    commande_BT_Serie();
    readLFSsensors();    
    switch (mode)
  {
    case ARRETE: 
      motorStop();
      BT1.print("The End");
      previousError = error;
      break;

    case PAS_DE_LIGNE:  
      motorStop();
      motorTurn(LEFT, 180);
      previousError = 0;
      break;

    case SUIVEE_LA_LIGNE:     
      Suiveurligne_Ultrasons();   
      break;  
      
    case ULTRASONS:
      modeUltrason();
      break;
  }
}
